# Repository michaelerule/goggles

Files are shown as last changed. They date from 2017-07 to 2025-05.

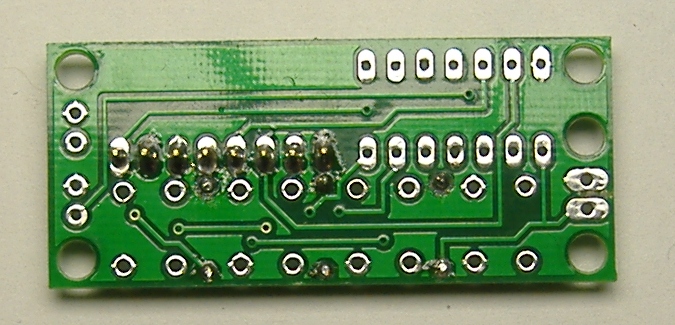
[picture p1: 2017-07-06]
media/visor media/assemble/DSCF3167.JPG

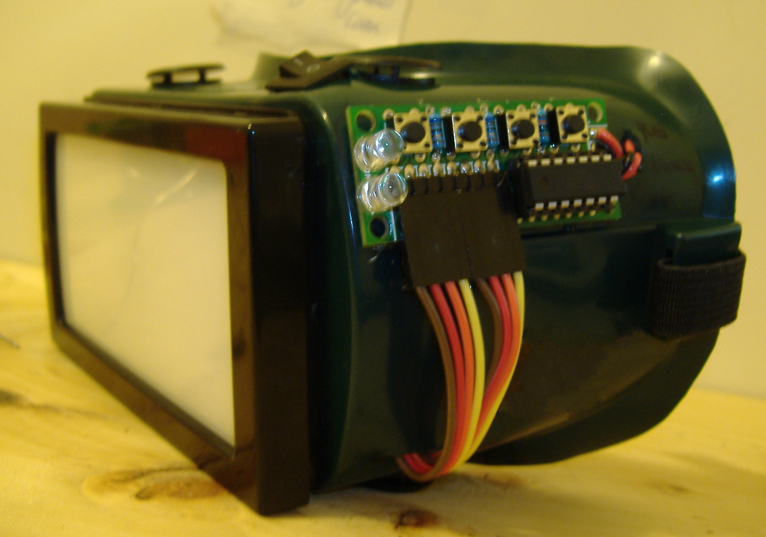
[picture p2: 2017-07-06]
media/visor media/assemble/DSCF3302.JPG

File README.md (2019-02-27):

# Goggles

Firmware and documentation for flicker-phosphene hallucination goggles. Some of the content here can be rendered as HTML, and a browsable website version of this repository can be [accessed through Github pages](https://michaelerule.github.io/goggles/).

This material follows earlier [blog posts](http://wealoneonearth.blogspot.co.uk/2009/09/how-to-build-goggles.html) outlining construction of do-it-yourself goggles to demonstrate the [flicker phosphene](http://journals.plos.org/ploscompbiol/article?id=10.1371/journal.pcbi.1002158) hallucination effect. A small batch of a [simplified re-design using welding goggles](http://treehovse.blogspot.co.uk) was produced a few years ago. 

Unless otherwise specified, media, text, and rendered outputs are licensed under the [Creative Commons Attribution Share Alike 4.0 license](https://choosealicense.com/licenses/cc-by-sa-4.0/) (CC BY-SA 4.0). Source code is licensed under the [GNU General Public License version 3.0](https://www.gnu.org/copyleft/gpl.html) (GPLv3). The CC BY-SA 4.0 is [one-way compatible](https://creativecommons.org/compatiblelicenses) with the GPLv3 license. The intent of this licensing choice is to encourage academic norms for citation and attribution. 

This project is published in the spirit (but not the letter) of the [tongue-and-cheek CRAPL license for academic code](http://matt.might.net/articles/crapl/CRAPL-LICENSE.txt). This is not a legal license as it contains internal inconsistencies (like forbidding users to exist). However, it contains a strong caution that this project has not been reviewed or prepared for use by the general public. If there is community interest in a specific subset of the project, please open an issue for improving the organization and documentation.

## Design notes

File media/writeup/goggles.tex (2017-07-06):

\documentclass[11pt]{scrartcl}

\newenvironment{itemised}{
\begin{itemize}
  \setlength{\itemsep}{1pt}
  \setlength{\parskip}{0pt}
  \setlength{\parsep}{0pt}
}{\end{itemize}}

\usepackage{hyperref}
\hypersetup{
    colorlinks,
    citecolor=black,
    filecolor=black,
    linkcolor=black,
    urlcolor=black
}

\setlength{\parskip}{0pt}
\setlength{\parsep}{0pt}
\setlength{\headsep}{0pt}
\setlength{\topskip}{0pt}
\setlength{\topmargin}{0pt}
\setlength{\topsep}{0pt}
\setlength{\partopsep}{0pt}

\usepackage{graphicx}
\setcounter{secnumdepth}{5}
\setcounter{tocdepth}{5}
\usepackage[margin=0.72in]{geometry}
\usepackage[utf8]{inputenc}
\usepackage{amsmath, amsthm, amssymb}
\usepackage{txfonts}
\usepackage{verbatim}
\usepackage{multirow}
\usepackage{booktabs}
\usepackage{indentfirst}

\usepackage{titlesec}
\titleformat{\subsubsection}[runin]% runin puts it in the same paragraph
       {\normalfont\bfseries}% formatting commands to apply to the whole heading
       {\thesubsection}% the label and number
       {0.5em}% space between label/number and subsection title
       {}% formatting commands applied just to subsection title
       [:]% punctuation or other commands following subsection title

\begin{document}
\title{The Goggles}
\subtitle{Kit information for James Rutter at AS220 Labs}
\author{Michael Rule}
\date{}
\maketitle
{\setlength{\parindent}{0cm}{This archive contains all information necessary to produce \emph{The Goggles} hallucination visor kits.}}
\tableofcontents
\newpage
\section{Parts and sources}
\subsection{Parts List}
\begin{itemised}
\item 1 Welding Goggles, "Fixed Front" with square window. Suggest: ``Crews'' brand from MRO supply.
\item 3 1/4'' translucent acrylic laser-cut panels
\begin{itemised}
	\item 1 visor outer panel with quasicrystal design
	\item 1 visor middle panel with LED placement markings
	\item 1 visor inner panel with cutaway for wires
	\end{itemised}
	\item 1 2xAAA battery pack
	\item 1 Visor controller printed circuit board
	\item 1 pre-programmed AtTiny24 microcontroller chip
	\item 1 14 pin DIP chip socket
	\item 1 8-pin right angle male header
	\item 2 4-pin female jumper cables
	\item 2 RGB LEDs
	\item 2 Indicator LEDs, 5 or 3mm, flexible options :
	\begin{itemised}
	\item 1 Blue LED, 1 Ultraviolet LED
	\item 1 Color-Change LED, 1 LED with 3.3 forward voltage ( blue, UV, white, some green )
	\end{itemised}
	\item 2 68$\Omega$ resistors	
	\item 1 10K$\Omega$ resistor   	
	\item 4 6mm through-hole tactile switches
	\item 1 toggle power switch ( small rocker style )
	\item 1 4" to 6" length of 22 gauge wire
	\item 2 60-100mm zip ties
	\item 1 1x2'' (appx) velcro tape
	\item 1 13x18 cm${}^2$ anti-static bag for packaging
\end{itemised}
\newpage
\subsection{Sources}
\subsubsection{Welding Goggles}
Welding Goggles, ``Fixed Front'' with square window. It is important that the model of goggles be designed to fit up to three filter three filter lenses with a gap in the middle. We have previously used  \href{http://www.shoplet.com/Crews-Welding-Goggles-20050/SEPTLS13520050/spdv}{Crews 105-20050} welding goggles. They are the cheapest goggles that meet this requirement. Their price is between \$3 and \$10.   If you use a different product, get a sample and test whether the kit works with that design. MRO center has the best price if ordering large quantities, but their website is hard to navigate. I have seen this item listed twice on their website with over \$2 difference in price. Searching for "Crews Welding Goggles" through google seems to be good about finding the cheapest source.
\subsubsection{1/4'' translucent acrylic laser-cut panels}
You want the ``intermediate'' translucency quarter-inch acrylic panels. I picked mine up from RISD materials store. On some days, there is someone at the store who will cut large sheets down to laser cutter size for you. 
If not, you will have to do it yourself using an acrylic knife or band saw. AS220 Epilog bed size is 18x22''. Cheap-Chinese mystery laser, which was used for the first production run, has a 12''x12'' bed size.
\subsubsection{2xAAA battery pack}
These are available from all electronic distributors ( Mouser, Digikey ), and also available wholesale from China via ebay. Current design uses an open-clip plastic model. The holes on the bottom of this model allow for some flexibility when mounting, and the 3D printed parts have been designed with this form in mind. The small size also lets you keep the batteries on the inside, if you wish.
\subsubsection{Visor controller printed circuit board}
These much be orderd from GoldPhoenix online. The smallest order is 93 boards for USD114. The necessary EagleCad and Gerber files are in this archive. Instructions for purchasing a batch from GoldPoenix can be found on their website. Payment is through PayPal, with ``mass payment'' providing a USD3 discount. Lead time is approximately two weeks.
\subsubsection{pre-programmed AtTiny24 microcontroller chip}
Any of AtTiny24/44/84 will work with this design. I purchase through Mouser.
\subsubsection{14 pin DIP chip socket}
A socket for the microcontroller is not mandatory, but is convenient. It reduces the chance of destroying the microcontroller while soldering, especially for less experienced solderers, and makes it easier to reprogram the device ( although in-place programming is possible with this circuit ). I purchased these from Mouser but they are also very cheap from Futurlec. Ebay is sometimes the best price for this component, after considering shipping.
\subsubsection{8-pin right angle male header}
There are at least three versions of single-row right-angle male break-away headers floating around. We want the ones that Sparkfun sells. These have a plastic buffer that raises the pins to the perfect height to accept a female 4-pin jumper. Check datasheets before you buy. My first order from Futurlec provided headers that were unsuitable. 
\subsubsection{4-pin female jumper cables}
These are not available from any of the major domestic distributors. Ideally, you are looking for 20cm ( 200mm ) long cables, although 30cm may be tolerable. Most of the 30cm cables will be loose wires in an ugly color. \href{http://www.seeedstudio.com/depot/4-pin-dualfemale-jumper-wire-300mm-5-pcs-pack-p-97.html}{Seed studio has them for USD0.60}. \href{http://www.elechouse.com/elechouse/index.php?main_page=product_info&cPath=105_108&products_id=433}{Elechouse is also USD0.60}. \href{http://www.aliexpress.com/store/product/4-Pin-Dual-female-Jumper-Wire-wire-length-200mm-5pcs-bunch/505390_539192964.html}{Ali express has them for USD0.21, but they double their prices in shipping}. Ebay still seems to be the cheapest option. 
\subsubsection{Indicator LEDs} There is flexibility in the indicator LEDs. Both 3mm and 5mm sizes fit, although 3mm fits and looks better. The LEDs need to be able to tolerate up to 3.3V forward volatage, which wil limit you to blue, violet, white, and color-changing LEDs. Color-changing LEDs are cool but expensive. If you use a color changing LED for the play/shuffle indicator, it will be phase reset frequenty -- which may or may not be desirable. 
\subsubsection{Other Components} The remaining components are available from any major distributor, but again, the best prices appear to be on Ebay with no obvious loss in quality.

\subsection{Costs}
Table 1 outlines an optimistic cost estimate for sourcing 93 kits. Most of the cost lies in the boards, the goggles themselvs, laser cutting, microcontrollers, and the jumper wires to the RGB LEDs. A good strategy is to purchase cheap components in lots of 100 then purchase more expensive items as needed. Prices based on a sale for the welding goggles which may not always be available.
\begin{table}[h]
\centering
\begin{tabular}{llllllll}
Item & Source & cost & units & \$/item & items & unit cost\\
\toprule
6mm tactile switch & Ebay & \$16.00 & 400 & 4 & 100 & \$0.17\\
PCB & GoldPhoenix & \$114.00 & 93 & 1 & 93 & \$1.23\\
10k resistor & Ebay & \$1.50 & 100 & 1 & 100 & \$0.02\\
68ohm resistor & Ebay & \$3.69 & 200 & 2 & 100 & \$0.04\\
LED1 & Ebay & \$7.80 & 100 & 1 & 100 & \$0.08\\
LED2 & Ebay & \$5.80 & 100 & 1 & 100 & \$0.06\\
RGB LED & Ebay & \$28.50 & 200 & 2 & 100 & \$0.31\\
14 pin DIP socket & Ebay & \$6.70 & 100 & 1 & 100 & \$0.07\\
4 pin 20cm f-f jumpers & aliexpress & \$94.92 & 200 & 2 & 100 & \$1.02\\
attiny24 & Mouser & \$88.20 & 100 & 1 & 100 & \$0.95\\
rocker switch & Ebay & \$18.89 & 100 & 1 & 100 & \$0.20\\
right-angle male headers & Sparkfun & \$50.00 & 100 & 1 & 100 & \$0.54\\
battery holder & Ebay & \$27.99 & 100 & 1 & 100 & \$0.30\\
crews welding goggles & MRO supply & \$360.64 & 100 & 1 & 100 & \$3.88\\
bags & Ebay & \$15.89 & 100 & 1 & 100 & \$0.17\\
anti static foam & Ebay & \$68.75 & 100 & 1 & 100 & \$0.74\\
acrylic & AS220 & \$100.00 & 100 & 1 & 100 & \$1.08\\
batteries & Ebay & \$44.99 & 200 & 2 & 100 & \$0.48\\
velcro & Ebay & \$8.74 & 100 & 1 & 100 & \$0.09\\
zip ties & Ebay & \$2.43 & 200 & 2 & 100 & \$0.03\\
 \bottomrule
TOTAL & & \$1,065 & & & 93 & \$11.46\\
\end{tabular}
\caption{Highly optimistic cost estimate using all lowest cost sources}
\label{}
\end{table}

\newpage
\section{Firmware source code and uploading}
The source for The Goggles firmware is in the \emph{software} sub-directory.
You need linux, avr-gcc, avrdude, and an AVR-ISP MkII to compile and upload. Uploading instructions are in a comment in the header of the source. The pinouts for connecting the AtTiny to an AVR ISP MkII are repeated below.
\begin{description}
\item[goggles-24.c] Default flicker-hallucination program for AtTiny24.
\item[goggles-24-calm.c] Opens with constant color patches in case you want a partial ganzfeld, no flickering. 
\end{description}
The script "go" runs on linux-like systems ( require sh ) and does the following : 
\begin{itemised}
\item checks to see if your AVR is connected
\item compiles the source code
\item strips the source code down for transfer
\item copies the source code to the AVR
\end{itemised}
Things that might change :
\begin{itemised}
\item "go" assumes that you are using avrispmkII
\item "go" assumes that you are using AtTiny24. Adjust flags accordingly if not.
\item "go" assumes your programmer lies at /dev/ttyUSB0, this may change, especially on macs.
\end{itemised}
\begin{verbatim}
    AtTiny24 pinout:               Programmer pinout, 
                                           6 pin:               10 pin:
                __ __
    3     VCC -|  U  |- GND    1     6 MISO +-+  VCC 3    3 vcc  +-+   MOSI 2
      BCK PB0 -|     |- PA0 G1       5 SCK  + + MOSI 2           + +    
      SHU PB1 -|     |- PA1 B1       4 RST  +-+  GND 1           + +]  RST  4
    4 RST PB3 -|     |- PA2 R1                                   + +   SCK  5 
      PLY PB2 -|     |- PA3 G2                            1 gnd  +-+   MISO 6
      FWD PA7 -|     |- PA4 B2 5 
    2 IND PA6 -|_____|- PA5 R2 6 
    
    Circuit:                                  __ __
                                         VCC-|  U  |-GND
              R-GBR-GB                GND-/ -|     |-----\
     _________||||||||___             GND-/ -|     |------(RGB1)-GND
    |o+++++++ |  ||  |  o|           VCC-www-|     |-www-/
    | +++++++ |__||__|(i)|            GNd-/ -|     |-----\
    |= [x] [<] [=] [>](p)|            GNd-/ -|     |------(RGB2)-GND
    |o__________________o|        GND-(LED1)-|_____|-www-/

                                         VCC-(LED0)-GND
\end{verbatim}

The buttons are as follows, from left to right :
\begin{itemised}
\item[$\times$] Shuffle      : if playing, toggle shuffled playback, else skip to random
\item[$<$] Skip Back    : skips to the previous light patch
\item[$=$] Play/Pause   : toggles automatic advancing through patches
\item[$>$] Skip Forward : advances to the next light patch
\end{itemised}

LEDs indicate :
\begin{itemised}
\item[i] -- indicator LED. on if playing, flashing if playing+shuffle
\item[p] -- power LED, on if powered on. 
\end{itemised}

\newpage
\section{CAD Files and instructions}
\subsection{Laser Cutting}\noindent Laser cutting .svg files are in the \emph{laser cut} sub-directory. The Goggles require 3 laser cut panels
\begin{itemised}
\item quasicrystal or blank patterned exterior panel
\item middle panel with LED placement marks
\item inner panel with notch for wiring
\end{itemised}
The outer and LED panels are cut in two passes. 
\begin{itemised}
\item shallow low-power pass etches vector graphics
\item high-power pass cuts out outline
\end{itemised}
These parts should be cut out of medium translucency 1/8'' acrylic.
Some files have both graphic and outline cuts and must be separated to cut. 
Both passes are vector cuts, not raster graphics. 
Some files have multiple panels with redundant edges removed for fast cutting. 
I suggest making a custom panel with this technique to fit the bed size.
There are also blank panels that can be used as templates for custom graphics.

\subsection{3D printing}
The sub-directory \emph{3d printed} contains two .stl files.
3D printed parts are not a core part of the kit, but rather an extension that
some with access to a 3D printer may want to print or build upon. 
These files contain a bracket for the batteries and board,
as well as a button pad to overlay the board. 
I recommend printing with very little (no) infill, and one or two shells,
using a translucent plastic ( natural ABS will work ) to let the indicator lights
shine through.

\subsection{PCB manufacture}
EagleCad design and Gerber files are in the \emph{PCB} sub-directory. The 'board.zip' archive contains everything needed to order from goldphoenix. Send that archive as-is to order more boards. Goldphoenix offers 1000cm${}^2$ for \$114, which gives you 93 boards at about \$1.25/board.

\section{Media}

\begin{description}
\item[media/instructions] HTML and PDF assembly instructions
\item[media/instructions/insert] Packaging insert
\item[media/artwork] Custom artwork, (c) Austin Redwood, Michael Rule
\item[media/photos] Assembly photos
\item[media/journal.pcbi.1002158.pdf] PLoS computational biology flicker-hallucination paper writeup
\item[media/writeup/optimistic\_cost\_estimate.ods] spreadsheet for cost table in this document
\item[media/writeup] source code for this document
\end{description}
\end{document}

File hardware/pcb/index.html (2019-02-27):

### Index of pcb

../
./Attiny14:24:84
./milledgoggles Arduino pro-mini

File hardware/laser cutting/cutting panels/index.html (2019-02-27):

### Index of cutting panels

../
10_inner copy 2.svg
10_inner copy.svg
10_inner.svg
10_inner_merged.svg
1x1_inner_merged.svg
2_inner_merged.svg
5_cluster_inner_merged.svg
5x1_inner_merged.svg
blank_2x1_merged.svg
blank_2x3.svg
blank_2x3_merged.svg
blank_2x4.svg
blank_2x4_merged.svg
clear4r.svg
clear4test.svg
clear4testPanel.svg
dead_simple.svg
LED_2x3.svg
LED_2x3_merged.svg
LED_2x4.svg
LED_2x4_merged.svg
notched.svg
notched4.svg
quasi_1x1.svg
quasi_2x3.svg
quasi_2x4.svg
quasi_2x4_panel.svg
quasi_eye_1-3-sparser-2x4.svg
quasi_eye_1-3-sparsest.svg
quasi_eye_1-3-sparsester.svg
quasiSpecial6-5.svg
tracequasi.svg

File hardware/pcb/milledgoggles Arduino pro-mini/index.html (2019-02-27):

### Index of milledgoggles Arduino pro-mini

../
drill.rml
mill.rml
Welding_board_3.ai
Welding_board_3.svg

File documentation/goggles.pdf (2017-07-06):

# The Goggles

Kit information for James Rutter at AS220 Labs

## Michael Rule

This archive contains all information necessary to produce The Goggles hallucination visor kits.

## Contents

1 Parts and sources | 2
2 Firmware source code and uploading | 5
3 CAD Files and instructions | 6
4 Media | 6

## 1 Parts and sources

### 1.1 Parts List

- 1 Welding Goggles, ”Fixed Front” with square window. Suggest: “Crews” brand from MRO supply.
- 3 1/4” translucent acrylic laser-cut panels

– 1 visor outer panel with quasicrystal design
– 1 visor middle panel with LED placement markings
– 1 visor inner panel with cutaway for wires
- 1 2xAAA battery pack
- 1 Visor controller printed circuit board
- 1 pre-programmed AtTiny24 microcontroller chip
- 1 14 pin DIP chip socket
- 1 8-pin right angle male header
- 2 4-pin female jumper cables
- 2 RGB LEDs
- 2 Indicator LEDs, 5 or 3mm, flexible options :

– 1 Blue LED, 1 Ultraviolet LED
– 1 Color-Change LED, 1 LED with 3.3 forward voltage ( blue, UV, white, some green )
- 2 68Ω resistors
- 1 10KΩ resistor
- 4 6mm through-hole tactile switches
- 1 toggle power switch ( small rocker style )
- 1 4” to 6” length of 22 gauge wire
- 2 60-100mm zip ties
- 1 1x2” (appx) velcro tape
- 1 13x18 cm²
anti-static bag for packaging

### 1.2 Sources

1.2 Welding Goggles: Welding Goggles, “Fixed Front” with square window. It is important that the model of goggles be designed to fit up to three filter three filter lenses with a gap in the middle. We have previously used Crews 105-20050 (http://www.shoplet.com/Crews-Welding-Goggles-20050/SEPTLS13520050/spdv) welding goggles. They are the cheapest goggles that meet this requirement. Their price is between $3 and $10. If you use a different product, get a sample and test whether the kit works with that design. MRO center has the best price if ordering large quantities, but their website is hard to navigate. I have seen this item listed twice on their website with over $2 difference in price. Searching for ”Crews Welding Goggles” through google seems to be good about finding the cheapest source.

1.2 1/4” translucent acrylic laser-cut panels: You want the “intermediate” translucency quarter-inch acrylic panels. I picked mine up from RISD materials store. On some days, there is someone at the store who will cut large sheets down to laser cutter size for you. If not, you will have to do it yourself using an acrylic knife or band saw. AS220 Epilog bed size is 18x22”. Cheap-Chinese mystery laser, which was used for the first production run, has a 12”x12” bed size.

1.2 2xAAA battery pack: These are available from all electronic distributors ( Mouser, Digikey ), and also available wholesale from China via ebay. Current design uses an open-clip plastic model. The holes on the bottom of this model allow for some flexibility when mounting, and the 3D printed parts have been designed with this form in mind. The small size also lets you keep the batteries on the inside, if you wish.

1.2 Visor controller printed circuit board: These much be orderd from GoldPhoenix online. The smallest order is 93 boards for USD114. The necessary EagleCad and Gerber files are in this archive. Instructions for purchasing a batch from GoldPoenix can be found on their website. Payment is through PayPal, with “mass payment” providing a USD3 discount. Lead time is approximately two weeks.

1.2 pre-programmed AtTiny24 microcontroller chip: Any of AtTiny24/44/84 will work with this design. I purchase through Mouser.

1.2 14 pin DIP chip socket: A socket for the microcontroller is not mandatory, but is convenient. It reduces the chance of destroying the microcontroller while soldering, especially for less experienced solderers, and makes it easier to reprogram the device ( although in-place programming is possible with this circuit ). I purchased these from Mouser but they are also very cheap from Futurlec. Ebay is sometimes the best price for this component, after considering shipping.

1.2 8-pin right angle male header: There are at least three versions of single-row right-angle male break-away headers floating around. We want the ones that Sparkfun sells. These have a plastic buffer that raises the pins to the perfect height to accept a female 4-pin jumper. Check datasheets before you buy. My first order from Futurlec provided headers that were unsuitable.

1.2 4-pin female jumper cables: These are not available from any of the major domestic distributors. Ideally, you are looking for 20cm ( 200mm ) long cables, although 30cm may be tolerable. Most of the 30cm cables will be loose wires in an ugly color. Seed studio has them for USD0.60. (http://www.seeedstudio.com/depot/4-pin-dualfemale-jumper-wire-300mm-5-pcs-pack-p-97.html) Elechouse is also USD0.60. (http://www.elechouse.com/elechouse/index.php?main_page=product_info&cPath=105_108&products_id=433) Ali express has them for USD0.21, but they double their prices in shipping. (http://www.aliexpress.com/store/product/4-Pin-Dual-female-Jumper-Wire-wire-length-200mm-5pcs-bunch/505390_539192964.html) Ebay still seems to be the cheapest option.

1.2 Indicator LEDs: There is flexibility in the indicator LEDs. Both 3mm and 5mm sizes fit, although 3mm fits and looks better. The LEDs need to be able to tolerate up to 3.3V forward volatage, which wil limit you to blue, violet, white, and color-changing LEDs. Color-changing LEDs are cool but expensive. If you use a color changing LED for the play/shuffle indicator, it will be phase reset frequenty – which may or may not be desirable.

1.2 Other Components: The remaining components are available from any major distributor, but again, the best prices appear to be on Ebay with no obvious loss in quality.

### 1.3 Costs

Table 1 outlines an optimistic cost estimate for sourcing 93 kits. Most of the cost lies in the boards, the goggles themselvs, laser cutting, microcontrollers, and the jumper wires to the RGB LEDs. A good strategy is to purchase cheap components in lots of 100 then purchase more expensive items as needed. Prices based on a sale for the welding goggles which may not always be available.

Item | Source | cost | units | $/item | items | unit cost
6mm tactile switch | Ebay | $16.00 | 400 | 4 | 100 | $0.17
PCB | GoldPhoenix | $114.00 | 93 | 1 | 93 | $1.23
10k resistor | Ebay | $1.50 | 100 | 1 | 100 | $0.02
68ohm resistor | Ebay | $3.69 | 200 | 2 | 100 | $0.04
LED1 | Ebay | $7.80 | 100 | 1 | 100 | $0.08
LED2 | Ebay | $5.80 | 100 | 1 | 100 | $0.06
RGB LED | Ebay | $28.50 | 200 | 2 | 100 | $0.31
14 pin DIP socket | Ebay | $6.70 | 100 | 1 | 100 | $0.07
4 pin 20cm f-f jumpers | aliexpress | $94.92 | 200 | 2 | 100 | $1.02
attiny24 | Mouser | $88.20 | 100 | 1 | 100 | $0.95
rocker switch | Ebay | $18.89 | 100 | 1 | 100 | $0.20
right-angle male headers | Sparkfun | $50.00 | 100 | 1 | 100 | $0.54
battery holder | Ebay | $27.99 | 100 | 1 | 100 | $0.30
crews welding goggles | MRO supply | $360.64 | 100 | 1 | 100 | $3.88
bags | Ebay | $15.89 | 100 | 1 | 100 | $0.17
anti static foam | Ebay | $68.75 | 100 | 1 | 100 | $0.74
acrylic | AS220 | $100.00 | 100 | 1 | 100 | $1.08
batteries | Ebay | $44.99 | 200 | 2 | 100 | $0.48
velcro | Ebay | $8.74 | 100 | 1 | 100 | $0.09
zip ties | Ebay | $2.43 | 200 | 2 | 100 | $0.03
TOTAL | | $1,065 | | | 93 | $11.46

Table 1: Highly optimistic cost estimate using all lowest cost sources

## 2 Firmware source code and uploading

The source for The Goggles firmware is in the software sub-directory. You need linux, avr-gcc, avrdude, and an AVR-ISP MkII to compile and upload. Uploading instructions are in a comment in the header of the source. The pinouts for connecting the AtTiny to an AVR ISP MkII are repeated below.

goggles-24.c Default flicker-hallucination program for AtTiny24.

goggles-24-calm.c Opens with constant color patches in case you want a partial ganzfeld, no flickering.

The script ”go” runs on linux-like systems ( require sh ) and does the following :

- checks to see if your AVR is connected
- compiles the source code
- strips the source code down for transfer
- copies the source code to the AVR

Things that might change :

- ”go” assumes that you are using avrispmkII
- ”go” assumes that you are using AtTiny24. Adjust flags accordingly if not.
- ”go” assumes your programmer lies at /dev/ttyUSB0, this may change, especially on macs.
AtTiny24 pinout: | Programmer pinout,
| | | | | 6 pin: | | | 10 pin:
__ __
3 | VCC -| | U | |- GND | 1 | 6 MISO +-+ | VCC 3 | 3 vcc | +-+ | MOSI 2
BCK PB0 -| | |- PA0 G1 | 5 SCK | + + MOSI 2 | + +
SHU PB1 -| | |- PA1 B1 | 4 RST | +-+ | GND 1 | + +] | RST | 4
4 RST PB3 -| | |- PA2 R1 | + + | SCK | 5
| PLY PB2 -| | | |- PA3 G2 | | | | 1 gnd | +-+ | MISO 6
FWD PA7 -| | |- PA4 B2 5
2 IND PA6 -|_____|- PA5 R2 6
Circuit: | __ __
VCC-| | U | |-GND
R-GBR-GB | GND-/ -| | |-----\
_________||||||||___ | GND-/ -| | |------(RGB1)-GND
|o+++++++ | | || | | | o| | VCC-www-| | |-www-/
| +++++++ |__||__|(i)| | GNd-/ -| | |-----\
|= [x] [<] [=] [>](p)| | GNd-/ -| | |------(RGB2)-GND
|o__________________o| | GND-(LED1)-|_____|-www-/

VCC-(LED0)-GND
The buttons are as follows, from left to right :

× Shuffle : if playing, toggle shuffled playback, else skip to random < Skip Back : skips to the previous light patch
= Play/Pause : toggles automatic advancing through patches
> Skip Forward : advances to the next light patch

LEDs indicate :

i – indicator LED. on if playing, flashing if playing+shuffle p – power LED, on if powered on.

## 3 CAD Files and instructions

### 3.1 Laser Cutting

Laser cutting .svg files are in the laser cut sub-directory. The Goggles require 3 laser cut panels

- quasicrystal or blank patterned exterior panel
- middle panel with LED placement marks
- inner panel with notch for wiring

The outer and LED panels are cut in two passes.

- shallow low-power pass etches vector graphics
- high-power pass cuts out outline

These parts should be cut out of medium translucency 1/8” acrylic. Some files have both graphic and outline cuts and must be separated to cut. Both passes are vector cuts, not raster graphics. Some files have multiple panels with redundant edges removed for fast cutting. I suggest making a custom panel with this technique to fit the bed size. There are also blank panels that can be used as templates for custom graphics.

3.2 3D printing

The sub-directory 3d printed contains two .stl files. 3D printed parts are not a core part of the kit, but rather an extension that some with access to a 3D printer may want to print or build upon. These files contain a bracket for the batteries and board, as well as a button pad to overlay the board. I recommend printing with very little (no) infill, and one or two shells, using a translucent plastic ( natural ABS will work ) to let the indicator lights shine through.

### 3.3 PCB manufacture

EagleCad design and Gerber files are in the PCB sub-directory. The ’board.zip’ archive contains everything needed to order from goldphoenix. Send that archive as-is to order more boards. Goldphoenix offers 1000cm² for $114, which gives you 93 boards at about $1.25/board.

## 4 Media

media/instructions HTML and PDF assembly instructions

media/instructions/insert Packaging insert

media/artwork Custom artwork, (c) Austin Redwood, Michael Rule

media/photos Assembly photos

media/journal.pcbi.1002158.pdf PLoS computational biology flicker-hallucination paper writeup

media/writeup/optimistic cost estimate.ods spreadsheet for cost table in this document

media/writeup source code for this document

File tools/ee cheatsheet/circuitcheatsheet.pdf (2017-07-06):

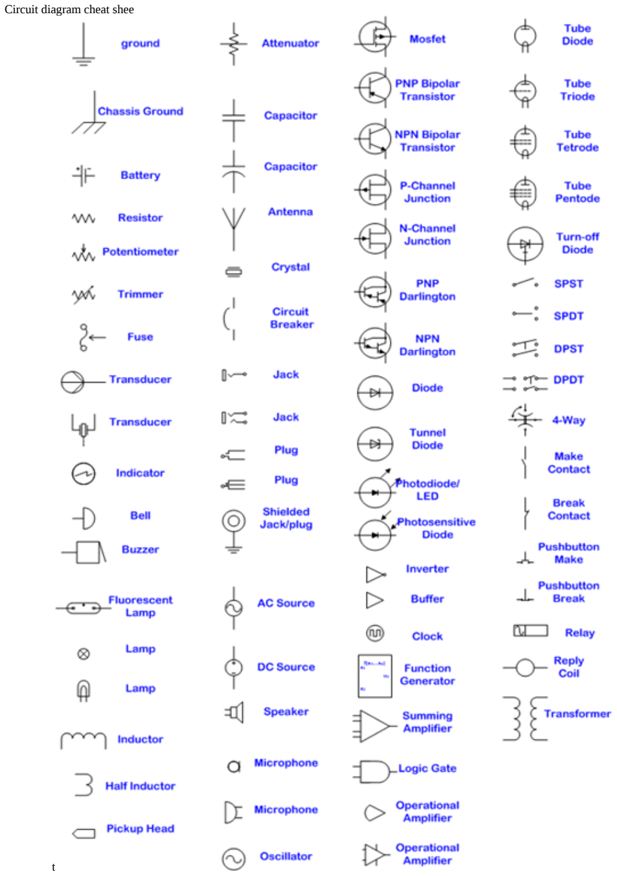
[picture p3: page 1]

Circuit diagram cheat shee

t

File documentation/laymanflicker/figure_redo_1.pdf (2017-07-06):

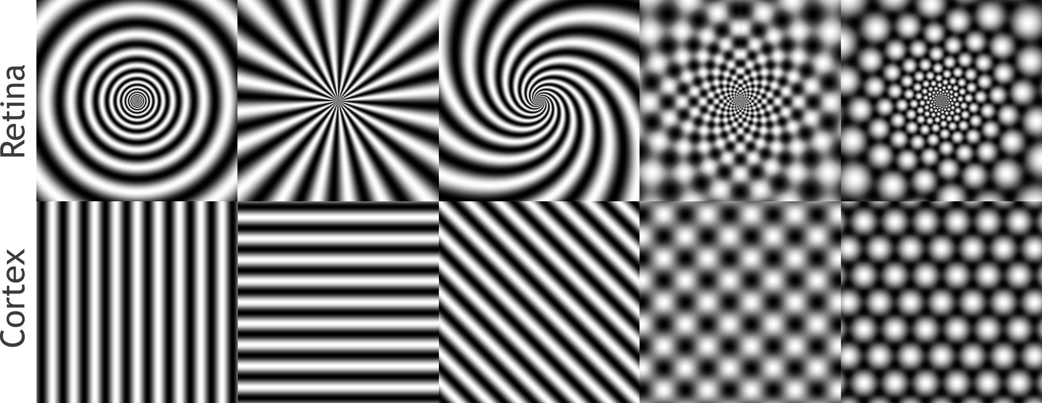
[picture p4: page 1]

RetinaCortex

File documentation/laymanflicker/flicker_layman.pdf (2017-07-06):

Geometric hallucinations induced by flickering light

Most people see colorful geometric patterns when looking at uniform flickering lights of a certain frequency. These patterns are subjectively described as “checkerboards” “ripples” “starbursts” “honeycombs”, sometimes taking on an overall tunnel-like appearance. It is striking how universal these patterns are – these simple flicker-induced geometric hallucinations are similar across individuals, and similar to certain visual hallucinations seen in visual-triggered epilepsy, migraine auras, and hallucinogens. A simple way to achieve such hallucinations is to close one's eyes and face toward the sun. Then, with fingers outstretched and separated, wave the hand back and forth in front of the eyes. Your fingers will create a flickering of the sunlight, which will be diffused and made uniform by closed eyelids.

The shortest primer on the visual system

To understand why flickering lights might trigger geometric hallucinations, and why the hallucinations should take on particular forms, we need to understand a little about the nervous system. A good review is beyond the scope of this article, but I attempt to give a short overview here.

Very briefly, the eye and the brain contain cells called neurons which are specialized for computation. Neurons communicate with each other in little all-or-nothing events called action potentials or “spikes”, which propagate along long “wires” called axons, extending away from the cell body. These spikes are picked up by other neurons with more local tree of wires called “dendrites”. When discussing a large number of neurons, people sometime just think of their average “firing rate” or “activity”, rather than individual spikes.

Early visual processing relates to the sort of geometric hallucinations that we can get out of the early visual system. Light enters the eyes and is picked up by photoreceptor cells. These cells communicate to neurons in the retina that compress visual input. We will focus on four aspects of this compression related to flicker induced geometric visual hallucinations:

(1) The RGB color-space picked up by the photo-receptors is converted to three contrasts : light-dark, yellow-blue, and red-green. The color-space conversion relates to how, for instance, a red-green flicker is especially effective at eliciting hallucinations.
(2) The image is converted to a form focusing on edges and contrasts – uniform areas are ignored. This band-pass nature of early visual processing relates to how neurons are connected in the visual cortex, which in turns determines what size “waves” might appear in geometric visual hallucinations.
(3) The retina has band-pass properties in time as well: slowly changing visual inputs are not registered. This is important for the temporal aspect of flicker induced hallucinations. Certain speeds of flickering will be picked up and transmitted better.
(4) The eye has the greatest resolution in the very center, and the resolution drops off toward the periphery. This is why, for example, it is difficult to read things out of the corner of your eye. The brain also devotes less space to processing the periphery. The way that the visual field is “unfolded” in the brain determines the subjective appearance of spontaneous ( hallucinated ) neural activity.

A theory of geometric visual hallucinations

A theory on the origin of geometric visual hallucinations comes from Ermentrout and Cowen (1979), and briefly, makes the following hypotheses:
– The tunnel-like appearance of the overall hallucination relates to how the brain maps the visual field. – Patterns like checkerboards and honeycombs arise from superposition of multiple waves
– Local interactions in the brain generate wave-like patterns of activity

The two halves of the visual field are split apart and each processed in one half of the brain. The brain devotes more processing power toward the center of the visual field. The net effect is to “unfold” the circular visual field from the retina into a “strip” of the brain at the back called the primary visual cortex. The result is that tunnel-like visual inputs map to simple regular patterns in the brain, and the inverse: hallucinated simple regular patterns in visual cortex are subjectively experienced as tunnel-like visual inputs.

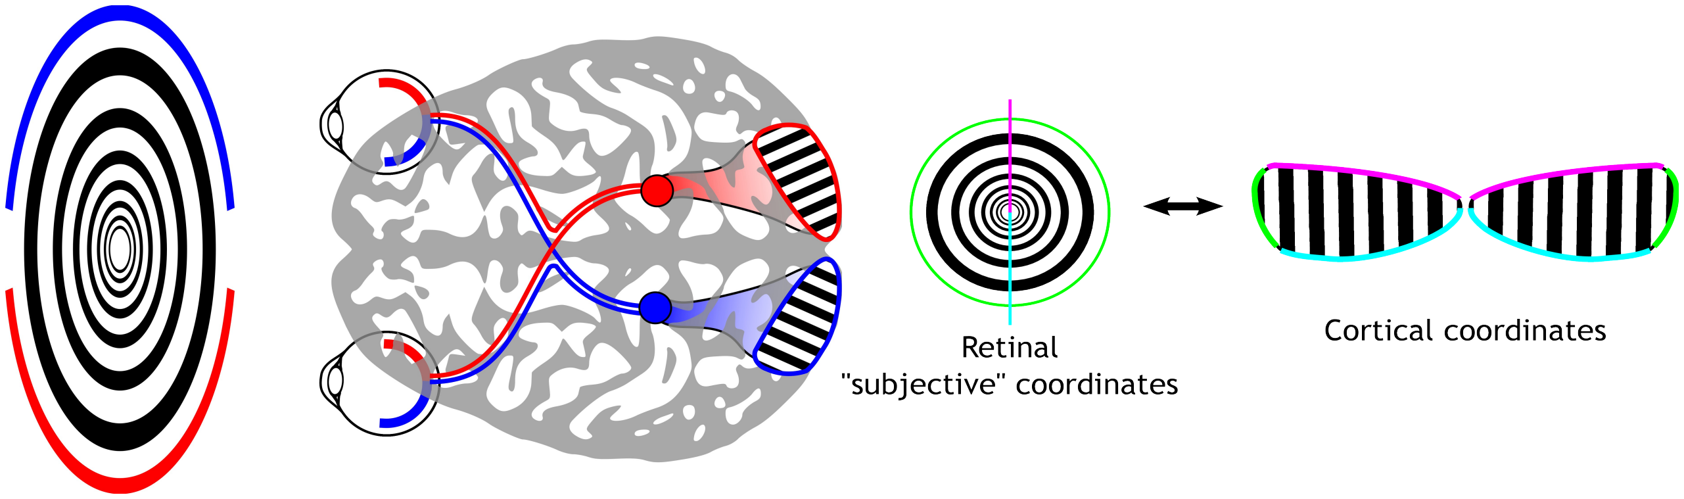
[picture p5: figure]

Stripe-like waves of activity in the brain are sufficient to explain circular, spiral, and starburst hallucinations. Checkerboards can be explained as the sum of two waves at right-angles, and honeycombs can be explains as the sum of three evenly spaced plane waves.

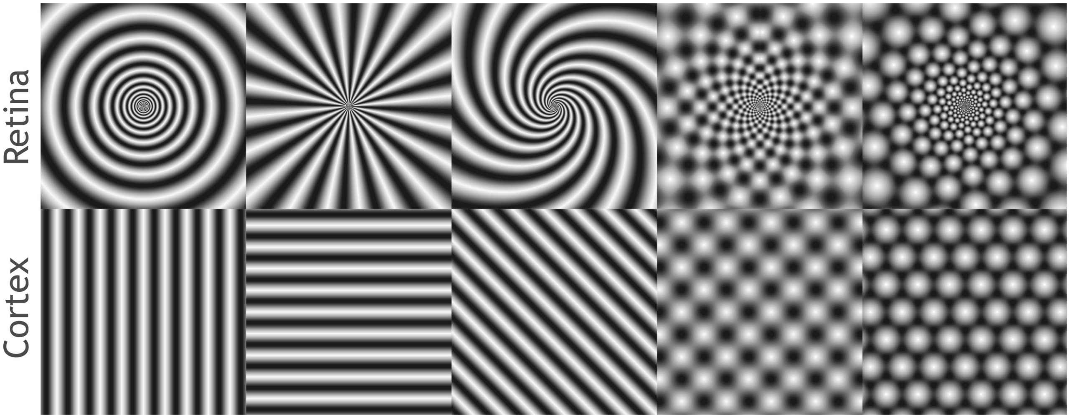
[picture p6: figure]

As to why the brain should spontaneously form waves of activity – that is something of an open question. Qualitatively, one can of it as the brain trying to “find” patterns in an image. Under certain circumstances, the pattern finding circuitry becomes unstable, and tends toward these simple, wave-like

patterns.

Driving the brain with a uniform, flickering input

Flickering light is believed to excite patterns using a resonance effect that pushes visual cortex outside of its normal operation. Neural activity in the brain oscillates spontaneously. There is a natural 8-12Hz oscillation in the visual system called the “alpha rhythm”. Providing visual input at this frequency is believed to excite this intrinsic oscillation. Other frequencies work as well, and may interact with other intrinsic oscillations. Stimulation at 8-25Hz also works to excite the alpha oscillation. Even though this is twice the intrinsic frequency of the system, local patches of the brain are hypothesized to respond only to every-other oscillation cycle, effectively oscillating at alpha. These frequencies vary from person to person and factors not completely understood, and there may be other processes contributing to flicker hallucinations that we have yet to understand.

Modeling the visual system as a “neural field”

Why does making visual cortex “resonate” with a stimulus lead to pattern formation?

[[ I don't know how to treat this without a lot of technical detail ]]

The response of a neural field model to uniform, flickering stimuli

[[ I don't know how to treat this without a lot of technical detail ]]

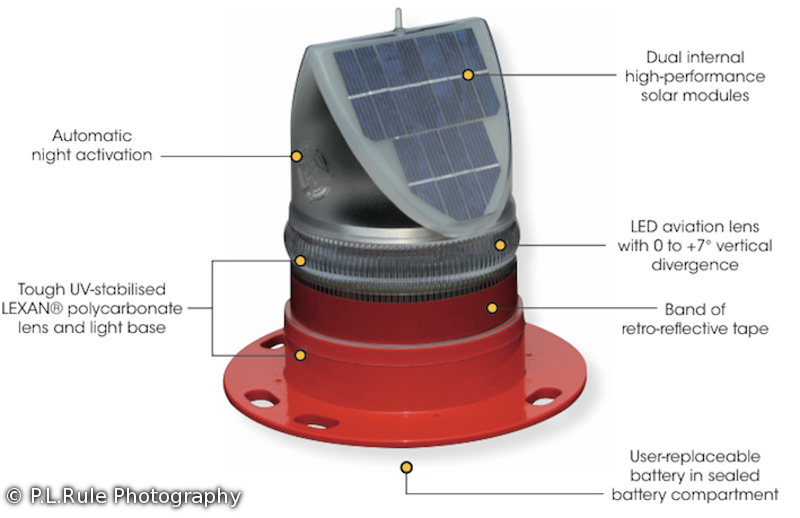
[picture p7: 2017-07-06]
tools/ee cheatsheet/media/Technical LED Color Chart_files/watermarked 105010_specs_pic_large.png

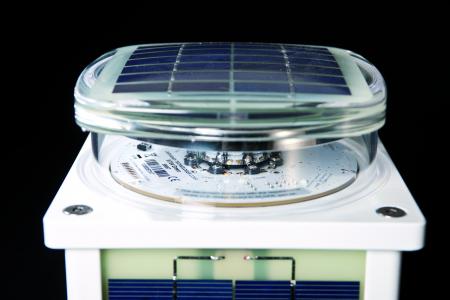
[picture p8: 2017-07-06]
tools/ee cheatsheet/media/Technical LED Color Chart_files/1029684-specs_large.JPG

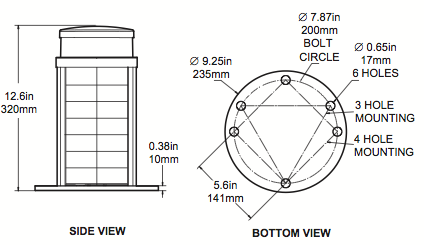
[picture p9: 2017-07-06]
tools/ee cheatsheet/media/Technical LED Color Chart_files/1029684-specs4_large.jpg

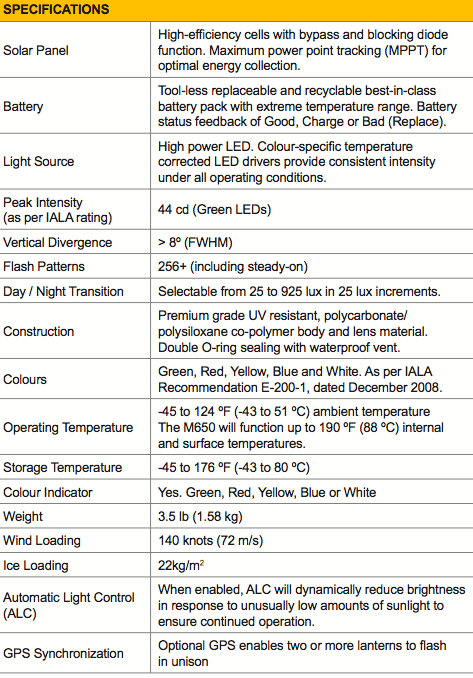
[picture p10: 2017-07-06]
tools/ee cheatsheet/media/Technical LED Color Chart_files/102943-specs7_large.jpg

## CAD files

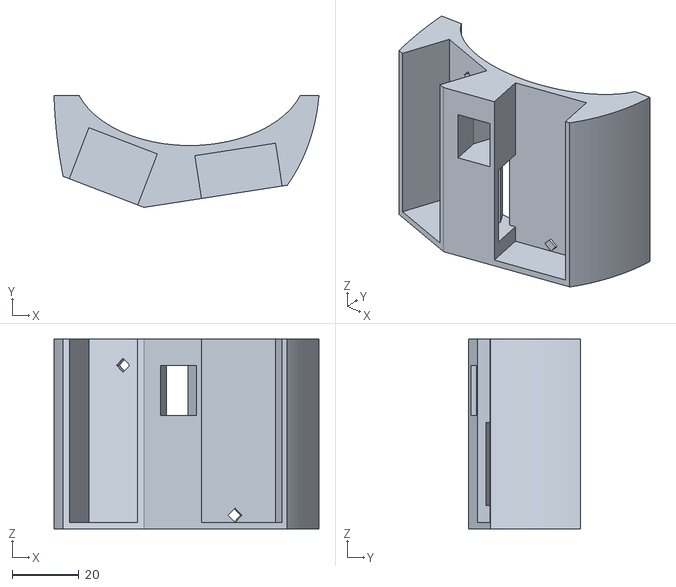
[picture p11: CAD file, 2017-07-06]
hardware/3d printing/3d printed/g1.stl
79.5 x 33.6 x 57.0

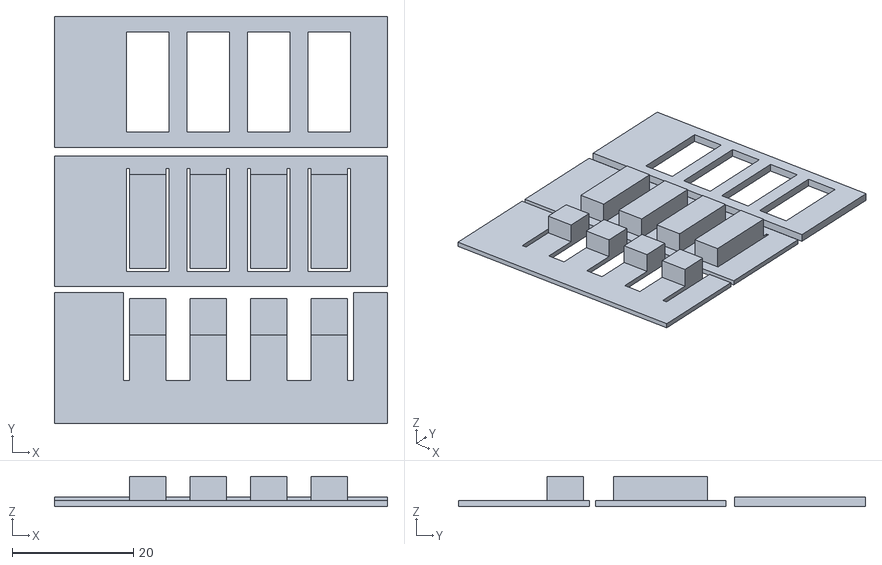
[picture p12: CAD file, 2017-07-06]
hardware/3d printing/3d printed/b1.stl
55.0 x 67.2 x 5.00

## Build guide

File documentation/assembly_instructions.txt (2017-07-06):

Assembly Instructions

Take a look at these pictures of the finished project to get a good idea of how everything is going to fit together when it's done.

Phase 1: The board

Prepare you soldering station and heat up your soldering iron. 

Make sure you have all parts pictured here. Listed from top to bottom, left to right, in the picture shown :

A   1 5" length of 22 gauge wire
B   2 RGB LEDs
D   2 68Ω resistors
C   1 10KΩ or 100KΩ resistor
E   1 2xAAA battery pack
F   1 pre-programmed AtTiny24 microcontroller
G   1 14 pin DIP chip socket
H   1 8-pin right angle male header
I   1 Visor controller printed circuit board
J   1 Blue LED
K   1 Ultraviolet LED
L   1 toggle power switch
M   4 tactile switches
N   2 4-pin female jumper cables

Locate the three resistors and bend the leads at a right angle close to the body, as shown. The LED resistors are 68ohm ( blue grey black gold ). The reset pull-up resistor is 100Kohm ( brown black orange gold ). However, as these were ordered from China, the markings are a bit unusual, and instead look like brown, black, black, orange, gold. The resistor value is, however, correct. Insert the resistors into the board. The two 68 ohm resistors go on the right, at shown, in the slots marked "LED". The reset pull-up resistor goes in the slot on the left marked "10k". Optionally bend the leads outward to hold the resistors in place while you solder them. Solder the resistors, and trim the excess leads with a wire cutter.

Place the 8-pin right-angle connector for the RGB LED cables as shown. Note that the plastic part of the header should surround the part of the header that is parallel to the board. Turn the board over and solder the 8-pin right angle connector. A common trick to get the connector flush against the board is to solder one pin. Then, melt that solder joint while pressing the connector flush against the board, and let it cool again. Solder the remaining pins.

Place the tactile switches on the board as shown. Note that, if the tactile switches are places sideways, the board will not function. 

Solder the chip socket. Note that there is a U shaped notch in one side of the socket. This indicates the orientation of the socket. Place the socket so that this notch is on the left as shown. One trick to get the socket flush against the board is to solder one corner pin, then melt that solder joint, position the socket so that it is flush, and let the joint cool. Then, do the same thing on the opposite corner. The socket is now held in place, leaving you free to solder the remaining pins.

Solder the indicator LEDs. It is important to insert these LEDs in the correct direction, otherwise they will not light. The LED has two leads. One leads is the "ground" LED. This lead will be shorter. IF you look closely at the plastic part of the LED, the base on one side will be flat. This also indicates the side of the LED with ground lead. In our case, thr ground lead should be at the top, as pictured here. Solder both indicator LEDs. One will be purple and one will be blue, but it does not matter which one goes where.

Trim any extra leads sticking out of the bottom of the board with wire snips.

Locate the AtTiny24 microcontroller chip. Note that one end of the chip has a U shaped notch, just like the socket. This indicates the orientation of the chip, and its important to insert the chip in the correct direction, otherwise the board will not work. The notch should be on the left as pictured. Carefully insert the microcontroller into its socket.

B : the goggles.

We are going to modify a pair of welding goggles to make the Visor. 

Slide the outer bracket of the goggles, and remove the tinted and clear plastic plates from the welding goggles. Leave the metal bracket.

Locate the translucent white plastic pieces that came with your kit. There should be three of them. One has a small notch cut into the side. This notch is for with LED wired, and will go inside. Another has a picture of some LEDs etched into the surface. This is the inner panel, and you will attach the LEDs to its surface. The third has a decorative pattern etched into its surface. This panel goes on the outside. 

Stack the inner panel on top of the decorative panel, so that the LED markings are on the bottom surface and the decorative markings are on the top. Place these pieces into the goggles where the tinted plastic used to be, and slide the bracket closed again. You should see a decorative pattern on the front of the goggles, and markings for positioning the LEDs on the inside of the goggles.

Get out your x-acto or hobby knife, and do be careful.

We are going to make some cuts into the goggles to pass wires through, and also a place to hold the power switch. 

Observe the markings in this picture. You can attach the electronics in many creative ways, but this is the way I assembled it. Wherever you decide to place the board, cut a small slit for the power wires near the power connector on the board ( the one remaining un-soldered place on the board ). Also, at some distance away from the 8 pin right angle connector for the LEDs, cut a 3/4" 1.5cm long slit for the LED cables. 

The power switch is best placed at the top, as pictured. Draw a rectangluar outline slightly smaller than the top of the power switch, and remove it with a x-acto knife. Try to insert the power switch into the hole for a test, and adjust the size of the hold if necessary.

Solder the red (+) wire from the battery pack onto one lead of the power switch, and the red jumper wire onto the other. Insert the power switch into the goggles as shown below.

Run the black ( -, ground ) wire from the batter pack, as well as the red (+) jumper wire connected to the switch, out through the slit you made for the power cables. 

We are going to solder the power wires into the board. Wires that are soldered directly onto the board often come loose. One simple way to make the connection stronger is to tie the wires to the board before you solder them. If you find this too challenging, it is not strictly necessary, as there shouldn't be too much strain on the power wires in typical use. 

Solder the power cables as shown, making sure that the red (+) wire goes into the hole labeled "+3v", and the black (-) wire in the other pad with the filled in white marking. Optionally, use the knot trick as shown to reduce strain on this solder connection.

If you have two AAA batteries, you can put them in the battery holder and turn on the power switch to see if the boiard works. The power-on LED should light up if everything is working correctly. If this does not happen, you will need to troubleshoot the board. Check that the indicator LEDs are inserted in the correct orientation, and that the red (+) wire from the batter is indeed connection to the +3v marked pad on the board. Look for loose or broken solder connections, and make sure the batteries you are using to test are charged.

Next, we are going to wire up and place the red, green, and blue (RGB) LEDs which generate the flickering light pattern.

Attach the jumper cables for the LEDs to the 8-pin connection as shown below. Their orientation does not matter, though for consistancy you should orient them the same way. Pat attention to the markings underneath the header, which have the labels "R", "G", and "B" for "red", "green", and "blue" color channels, as well as a filled-in white region indicating the groun (-) pin for the LEDs. You will want to rememebr which color wire corresponds to the ground pins for later.

Thread the jumper cables one after another through the slit you prepared earlier.

The inside of the goggles should now look something like this. Next we're going to insert the colored LEDs into the viewing area. These are the LEDs with four leads. In order, these leads are R(ground)GB. Examine the RGB LEDs closely. Like the indicator LEDs, one side of the plastic housing is flat on the bottom. As before, this indicates the side of the LED with the ground lead. You will want to insert the LEDs into the jumper cables such that the ground lead of the LED matches up with whicever color wire is the ground wire, which was noted in the previous step. 

You may optionally want to trim the LED leads to all the same length to make inserting the LEDs into the jumpers easier, or to adjust the spacing between the LEDs.

Turn on the goggles and test that the RGB LEDs are working. The first pattern on the goggles is a white flickering stimulus. If either LED does not appear white, you may have some missed connections. Try adjuting the LEDs and trimming the leads slightly if you are not getting a connection. If that fails, check that the jumpers are placed securely on the board header, and that the board header is soldered completely. If all color channels of both LEDs are working, turn of the goggles and proceed. 

Now, glue the LEDs in place as indicated by the etched markings, and as demonstrated here. Either super glue or hot glue will work. I found the gluing the ends of the jumpers together with a bit of super glue first made positioning easier. You may want to tack down the LED wires as shown to keep them in place. 

Insert the inner translucent plastic piece, feeding the wires out through the notch provided.

You're goggles are nearly complete ! The only thing left to do is to tie down some loose ends and hold everything in place.

Glue the battery pack in position as shown. 

Optionally glue the circuit board down to the outside of the goggles, or use the holes provided for other fasteners, perhaps zip ties. 

Organize the wires on the inside and move them out of the field of view. Tack everything down with some glue to hold it in place.

Thats it, you're done!

Power on the goggles and take note of the tacticle switches. They are, in order

-- shuffle
-- -- will jumpt to a random preset 
-- previous
-- -- will jump to the previous preset
-- play / pause
-- -- toggles automatic advancements through presets
-- next
-- -- will jump to the next preset

so, with that in mind, put on the goggles and take them for a spin

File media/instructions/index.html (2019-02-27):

### Index of instructions

../
./website
assembly_instructions.txt
goggles instructions narrow.pdf
insert.pdf
using the goggles

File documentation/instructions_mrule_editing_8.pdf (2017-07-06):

A word of warning :

THE VISOR IS NOT FOR EVERYONE. SOME PEOPLE HAVE A FROM OF EPILEPSY THAT CAN BE TRIGGERED BY FLICKERING LIGHTS. DO NOT USE THE VISOR IF YOU HAVE PHOTOSENSITIVE EPILEPSY.

Whats going on here?

Many people see geometric patterns when looking at flickering lights. The patterns depend on the frequency, color, and intensity of the flickering. People report seeing similar shapes, which are common in visual hallucinations and are called “form constants”. Flicker hallucinations are best induced using a totally immersive and uniform visual stimulation called a ganzfeld, which is German for “entire field”. Although the Visor is not a complete ganzfeld, it is immersive enough to demonstrate the flicker hallucination effect. The Visor has been carefully programmed and tuned to display a wide range of colorful patterns, allowing you to experience how geometric visual hallucinations change with frequency and color.

How does it work?

Flickering lights confuse the eye and the brain, causing them to misinterpret what they’re seeing. One hypothesis is that the flickering interacts with natural ongoing oscillations in visual cortex, exciting a specific frequency of brain waves. This increases the activity in visual cortex enough to overload the circuitry the brain uses for interpreting what it sees, causing you to see things that aren’t really there. One model has shown that flickering lights can cause visual cortex to behave like a ‘reaction diffusion system’, which is a type of system that spontaneously forms patterns. The most famous examples of biological reactiondiffusion systems are the patterns in animal fur, like leopard spots and zebra stripes. Some common geometric visual hallucinations induced in flicker hallucinations include stripes, checkerboards, hexagons, circles, and spirals. For a more detailed background, as well as a hypothetical mathematical model of the flicker hallucination effect, visit the publication linked at is.gd/qvMFol.

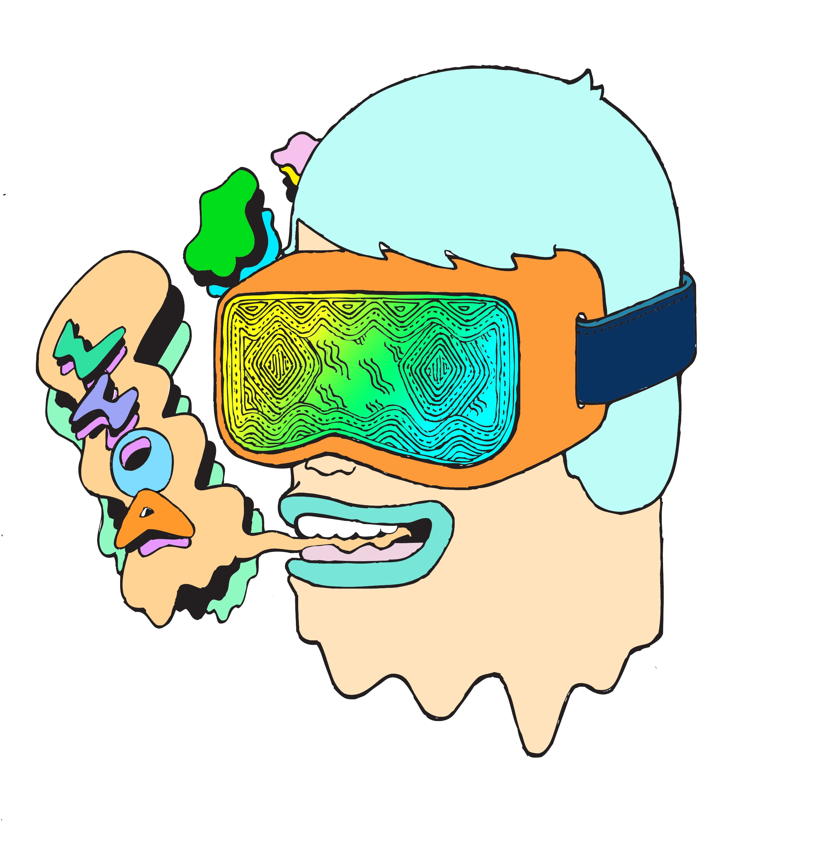
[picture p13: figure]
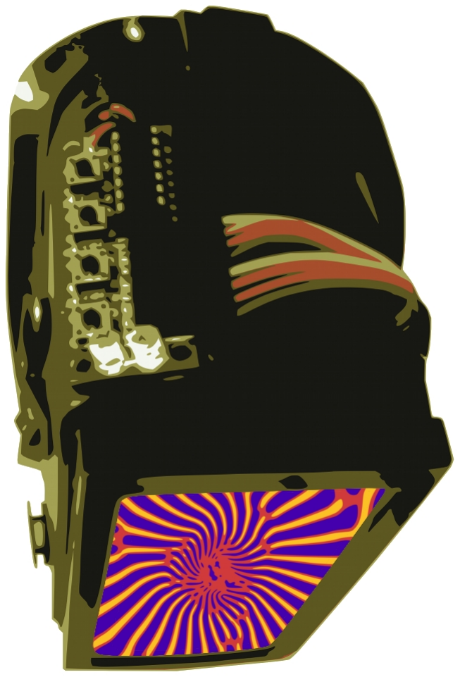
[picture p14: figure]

Assembly:

Assembly instructions are hosted online at treehovse.blogspot.com or is.gd/u5BvNb. Note that's treehovse with a 'v' instead of a 'u'. Visit this website to learn how to build your Visor kit.

In this parts bundle should be :

1 visor outer panel with quasicrystal design
1 visor middle panel with LED placement markings 1 visor inner panel with cutaway for wires
1 2xAAA battery pack
1 Visor controller printed circuit board
1 preprogrammed AtTiny24 microcontroller chip 1 14 pin DIP chip socket
1 8-pin right angle male header
2 4-pin female jumper cables
2 RGB LEDs
1 Blue LED
1 Ultraviolet LED
2 68 resistors Ω
1 10K resistor Ω
4 tactile switches
1 toggle power switch
1 4" to 6" length of 22 gauge wire

Along with your parts bundle, you should also have received one pair of welding goggles.

You will also need these tools and materials, not included in the kit :

A hot glue gun and hot glue sticks
A soldering iron and solder
Wire cutters
X-acto knife or hobby knife
optionally : super glue

Assembly instructions are hosted online at www.treehovse.blogspot.com, which is linked to the shortened URL is.gd/u5BvNb. Visit this website to learn how to build your Visor kit.

Experiment !

Once you have constructed the Visor, try drawing what you see, and comparing the experience with a friend. Start to experiment. Do different people see the same things? Does the experience seem to change when you are more alert, or more tired, or with open or closed eyes? Do you see the same patterns on the same presets across different days? If all of that gets too serious, the Visor also makes and excellent costume addition for partying, or simply creating a spectacle.

Usage Instructions:
Here is a cartoon of the board :

The buttons are as follows, from left to right :

Shuffle lights if playing, skip to random if paused Skip to the previous light patch
Play/Pause: toggles automatic playback
Skip to the next light patch

When first turned on, the goggles are paused at the first patch.
Press play/pause to begin the light sequence.
Press forward and back to move through the light patches.
Press shuffle to skip to a random patch when paused, or turn on randomized playback while playing.

The LEDs indicate :

is on if playing, flashing if playing with shuffle power LED is on if powered on.

When the goggles are paused, the indicator light will be off. When the goggles are playing, the indicator light will be on. When the goggles are playing back in a random order, the indicator light will be flashing.

The light program loops around to the beginning once it has reached the end. There are 120 patches.

When the batteries begin to die, the color balance will shift. In particular, the red channel will become dim. The goggles will continue to operate with low batteries, although the colors will change slightly. When the batteries get low enough, you may experience unpredictable behavior, such as random restarts. There goggles are not damaged from running with low batteries, but you should replace dying batteries when possible for optimal performance.

P

I

I
P

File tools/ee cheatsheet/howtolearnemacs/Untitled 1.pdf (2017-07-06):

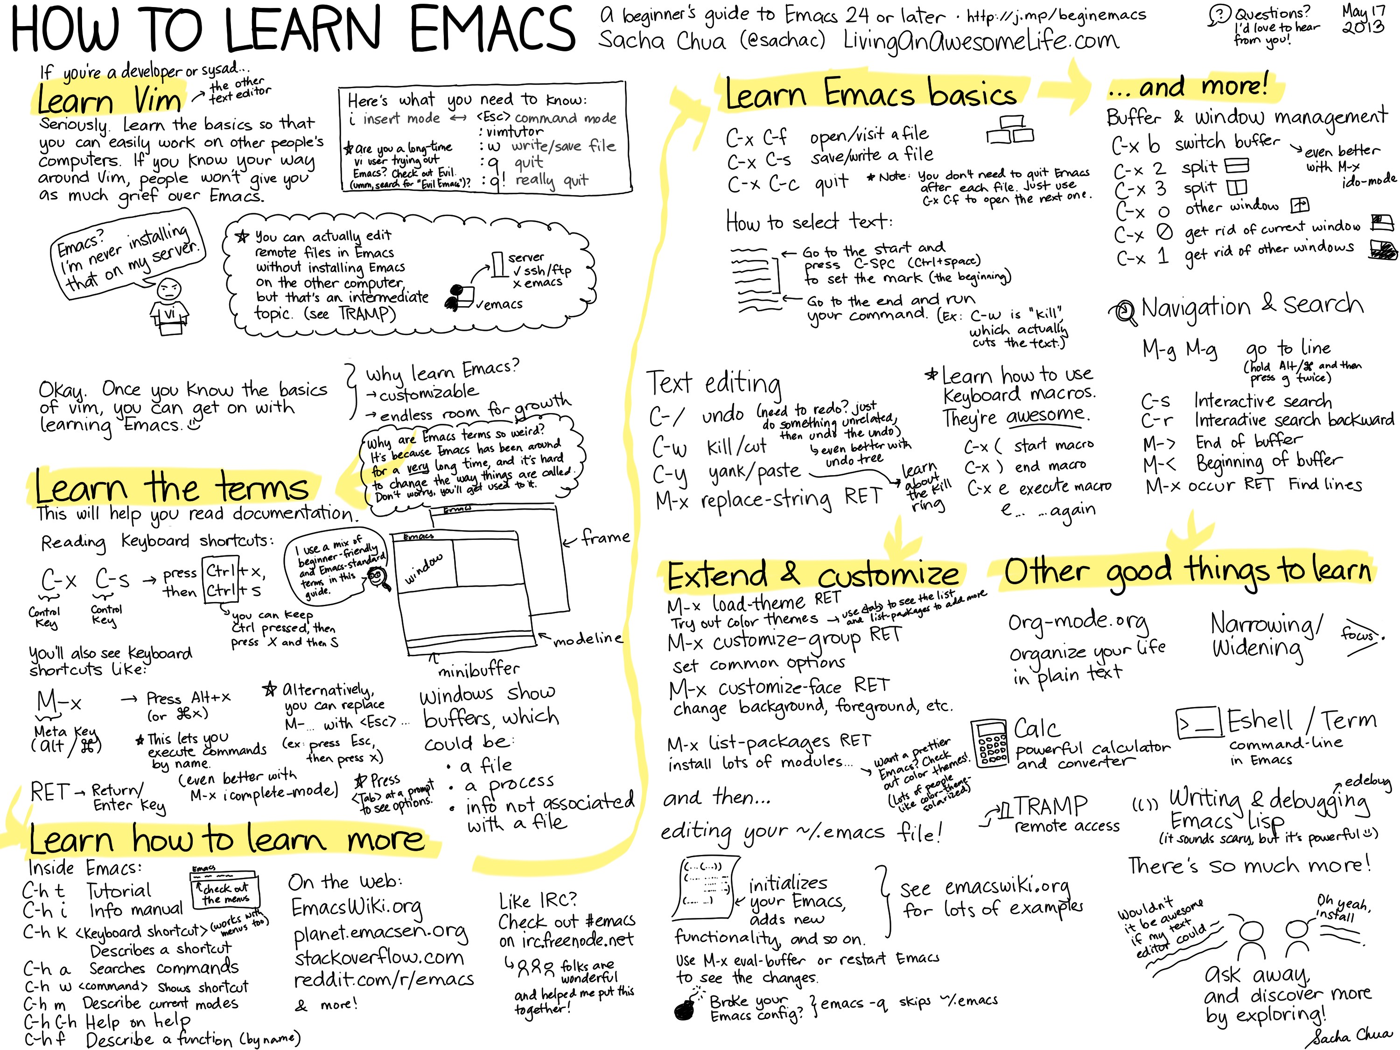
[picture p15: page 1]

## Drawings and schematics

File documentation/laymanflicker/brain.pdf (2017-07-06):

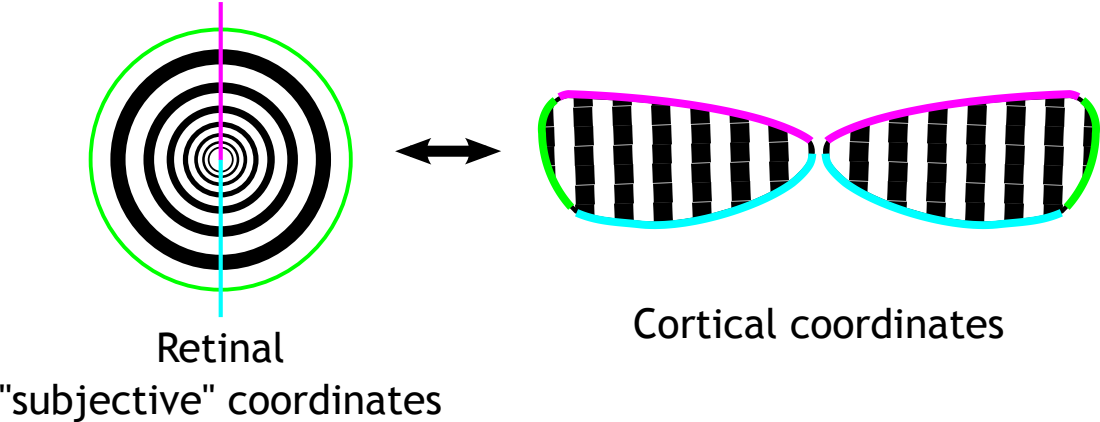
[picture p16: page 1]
Retinal "subjective" coordinates; Cortical coordinates

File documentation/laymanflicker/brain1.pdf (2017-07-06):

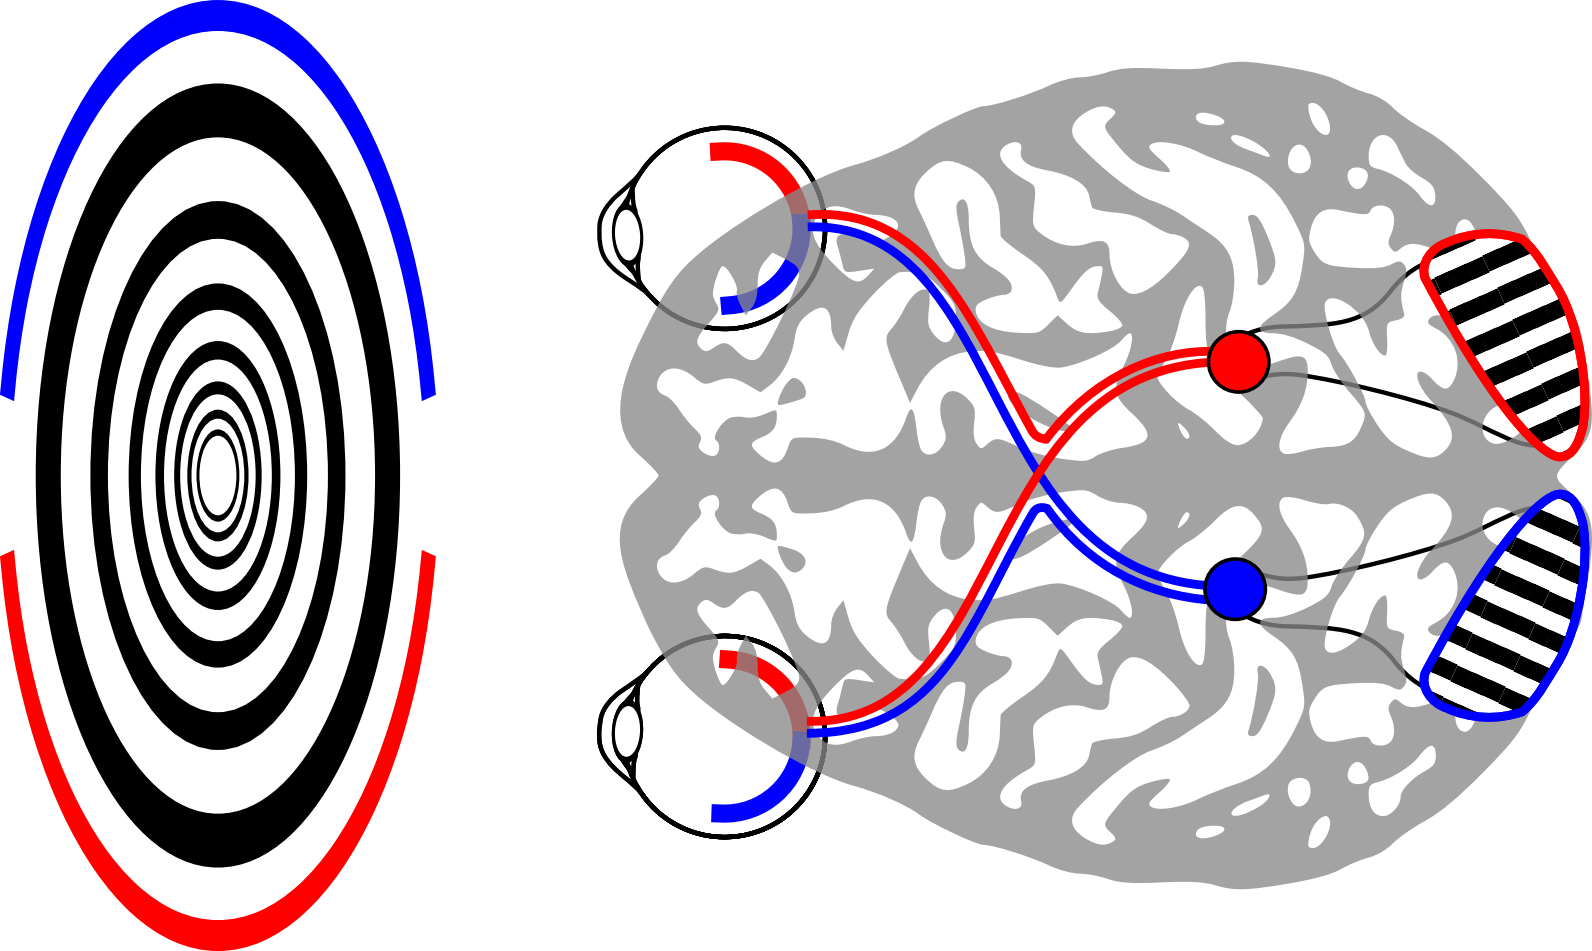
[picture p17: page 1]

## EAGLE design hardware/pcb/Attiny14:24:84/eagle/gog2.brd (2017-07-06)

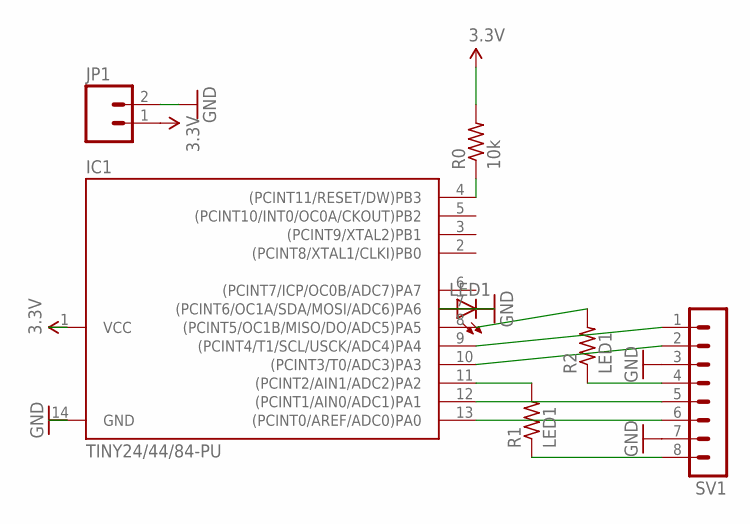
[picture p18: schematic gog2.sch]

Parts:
IC1: TINY24/44/84-PU; DIL14
JP1: M02; 1X02_LONGPADS
LED1: LED3MM
R0: 10k; 0207/7
R1, R2: LED1; 0207/7
SV1: MA08-1

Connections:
3.3V: IC1.1 (VCC), JP1.1, R0.2
GND: IC1.14 (GND), JP1.2, LED1.K (C), SV1.3, SV1.7
MISO: IC1.8 ((PCINT5/OC1B/MISO/DO/ADC5)PA5), R2.2
unnamed: IC1.7 ((PCINT6/OC1A/SDA/MOSI/ADC6)PA6), LED1.A
unnamed: IC1.11 ((PCINT2/AIN1/ADC2)PA2), R1.2
unnamed: R2.1, SV1.4
unnamed: R1.1, SV1.8
unnamed: IC1.13 ((PCINT0/AREF/ADC0)PA0), SV1.6
unnamed: IC1.12 ((PCINT1/AIN0/ADC1)PA1), SV1.5
unnamed: IC1.10 ((PCINT3/T0/ADC3)PA3), SV1.2
RESET: IC1.4 ((PCINT11/RESET/DW)PB3), R0.1
SCK: IC1.9 ((PCINT4/T1/SCL/USCK/ADC4)PA4), SV1.1

Board: 2 copper layers, 7 parts (1 on the bottom side), 12 nets, no tracks yet.

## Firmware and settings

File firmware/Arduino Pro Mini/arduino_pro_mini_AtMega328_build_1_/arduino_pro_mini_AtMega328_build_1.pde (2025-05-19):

#include <avr/pgmspace.h> //permits storing constant arrays in flash, giving us more RAM

/** Documentation
 *  Contents of this comment : 
 *  1 : Changes since last version
 *  2 : A note about representing things that arent integers on a 16 bit microcontroller
 *  3 : Light program language
 *  4 : layout of the remainder of this document
 *  
 *--- 0 : 20250503 Changes ------------------------------------------------------------
 *  I'm revisiting this 15 years later, trying to get the old Arduino pro-mini goggles
 *  builds to run again. 
 * 
 *  
 * 
 * 
 *--- 1 : Changes since last version --------------------------------------------------
 *  I made a few changes to the program, but the underlying structure is the same
 *  Superficial changes include making a new driver for the 4 character display, and
 *  defining some constants for use in the light program, to make things more readable.
 *
 *  The new display driver can scroll strings across the display. This is entertaining
 *  but is not used for anything important at the moment.
 *
 *  I also implemented Sine waveform lights ( which appear to be slightly less 
 *  effective at inducing geometric hallucinations ).
 *
 *  I added versions of the constant, squarewave, and sinewave lights that take
 *  six channels, RGB for the left and then RGB for the right eye. Patches that flash
 *  different colors, frequencies, or phases to different eyes produce amusing 
 *  effects ( well, no, not really, just different. disagreememnt between the inputs
 *  to the left and right eyes seem to weaken the ability to form patterns, at least
 *  to me)
 *
 *  I moved the light program into flash, so the program can now be much longer
 *  without filling up the RAM.
 *
 *  You no longer need to manually count the number of lights and change a constant
 *  to make the program work.
 *
 *  I removed a feature from the rendering code that normalized the light
 *  intensity per number of lights in a patch. This fixes a bug where in order
 *  to, say, alternate red and green lights, you would need to define two lights.
 *  the automatic normalization would then adjust both of these lights to half
 *  intensity. This creates the problem of making sure that the amplitude of the
 *  sum of lights in all channels never exceeds 255. For single light patches this 
 *  sould not be an issue. For multiple lights that may interfere, you will need to
 *  manually adjust light intensity so that the sum of the peaks of all waves is
 *  always less than 255 in all channels.
 *
 *  I have also restructured the program in a (slghtly) better way. Now intead of
 *  diving into a function which plays light patches, we crudely separate the work
 *  into a "light rendering thread" and a "display rendering thread", which are 
 *  interleaved in the main loop. This form of hard coded multithreading is common
 *  in embedded systems. New threads ( perhaps to poll input hardware or talk to 
 *  a computer attached to USB ) can be added to the main loop. At the moment all
 *  functions called from the main loop must usually take less than 10 ms, otherwise
 *  the light rendering will noticably stall.
 *
 *
 *--- 2 : A note about representing things that aren't ints on a 16 bit microcontroller
 *  The ATmega168 which drives your current version of the goggles can only perform 
 *  computations on up to 16 bit integers, no floating point is supported. 
 *  Because of this, in several points in the program, we use some number of low order bits
 *  as fractional bits to emulate fixed point decimal representations. This is done in a rather
 *  ad-hoc fasion, depending on the range of values we wish ro represent.
 * 
 *  Color values for R,G,B are in the range [0,1). This range is mapped to [0,255].
 *  multiplication of color values is provided by the FLOAT8MUL macro
 * 
 *  Frequency values are in the range [0,63] Hz and are mapped onto [0,255].
 *  This means that representations of the frequency code will appear to be 4x their
 *  actual value
 *
 *  Time durations of patches range from [0,31] and are mapped to [0,255].
 *  This means that representations of the duration of a patch will appear in units
 *  of one eights of a second. In hexidecimal notation, the second least significant
 *  digit will count half seconds, so that 0x40 represent 8 seconds.
 *
 *  Phase, in the range of [0,2*pi) is mapped to [0,255]. A phase shift of
 *  128 is equal to 180 degrees, 64 is equal to 90 degrees, and so on and so forth
 * 
 *  The output of the sine function [-1,1] is mapped to [0,255]
 *  is is convenient for generating sine wave output immediately suitable for display
 * 
 *  
 *--- 3 : Light Program Language ------------------------------------------------------
 * The goggles generate color based on a program stored in the flash array 
 * "program". This program consists of a series of patches. Patches are 
 * played in series, sequentially, until the end of the program. The program
 * starts over again once it is finished. Each patch begins with a byte
 * identifying the type of patch. The byte 0xff signals the end of the program.
 * All patches begin with a type identifier followed by a duration, measured
 * in eighths of a second. Data specific to different patch types follows.
 *
 * Currently Defined Types of Patch
 * 1 : default type : a collection of lights
 *     1 byte patch type ( which defines where to look for data )
 *     1 byte T the time duration in eigth seconds of the patch ( up to 32 seconds )  
 *     1 byte L number of active lights ( up to MAXLIGHTS )
 *     L light structs each with
 *       1 byte waveform type, which implies number and types of X bytes of parameters
 *       X bytes of parameters ( up to MAXPARAMS )
 *     next light up to L
 * 0 : patch link HARD TO USE, TODO : WRITE LIGHT PROGRAM GUI + "Compiler" 
 *     1 byte patch type ( which defines where to look for data )
 *     1 byte T the time duration in eighth seconds of the patch ( up to 32 seconds )  
 *     2 byte int referencing the header of a default patch
 * 255 : not a patch, but the end of the program ( loop back to beginning )
 *
 * The default patch type consist of a set of lights. There are many different
 * types of lights, with different parameters.  
 *
 *
 * Currently Defined Types of Light
 * 0 : 3 channel Constant 
 *     3 bytes of state [R,G,B]
 * 1 : 3 channel Square wave
 *     5 bytes of state [R,G,B,f,p]
 *       6 bytes of RGB (3 left, 3 right) color
 *       1 bytes frequency in quarter Hz
 *       1 bytes is a phase shift in 1/256ths of a cycle
 *       1 bytes cycle 255 = full 0 = off 128 = half //DUTY CYCLE NOT IMPLEMENTED !! IGNORE (TODO : IMPLEMENT IT)
 * 2 : 3 channel Sine wave
 *     5 bytes of state [R,G,B,f,p]
 *       6 bytes of RGB (3 left, 3 right) color
 *       1 bytes frequency in quarter Hz
 *       1 bytes is a phase shift in 1/256ths of a cycle
 * 3 : 6 channel Constant 
 *     6 bytes of state [Rl,Gl,Bl,Rr,Gr,Br]
 * 4 : 6 channel Square wave
 *     8 bytes of state [Rl,Gl,Bl,Rr,Gr,Br,f,p]
 *       6 bytes of RGB (3 left, 3 right) color
 *       1 bytes frequency in quarter Hz
 *       1 bytes is a phase shift in 1/256ths of a cycle
 *       1 bytes cycle 255 = full 0 = off 128 = half //DUTY CYCLE NOT IMPLEMENTED !! IGNORE (TODO : IMPLEMENT IT)
 * 5 : 6 channel Sine wave
 *     8 bytes of state [Rl,Gl,Bl,Rr,Gr,Br,f,p]
 *       6 bytes of RGB (3 left, 3 right) color
 *       1 bytes frequency in quarter Hz
 *       1 bytes is a phase shift in 1/256ths of a cycle
 * 
 * 7 segment LED notation
 * 0     _
 * 123  |_|
 * 456  |_|
 *
 *
 *--- 4 : Layout of the remainder of this document ------------------------------------
 * 
 * Light program readability #defines
 * Light program array
 * Lookup tables ( Sinewave, light type lengths & display lookup )
 * Program #defines
 * Program global variables & state
 * Main program logic ( setup & light rendering code )
 * Other utility functions
 * Display logic ( drivers and string functions )
 */
 
//////////////////////////////////////////////////////////////////////////////////////////////////////////////
///////  Light program readability #defines  /////////////////////////////////////////////////////////////////
//////////////////////////////////////////////////////////////////////////////////////////////////////////////
#define PATCH             (0x01)
#define END               (0xff)
#define CONSTANT          (0x00)
#define LINK              (0x00)
#define SQUARE            (0x01)
#define SINE              (0x02)
#define CONSTANT_6CHANNEL (0x03)
#define SQUARE_6CHANNEL   (0x04)
#define SINE_6CHANNEL     (0x05)

//////////////////////////////////////////////////////////////////////////////////////////////////////////////
///////  Light program array  ////////////////////////////////////////////////////////////////////////////////
//////////////////////////////////////////////////////////////////////////////////////////////////////////////
PROGMEM prog_uchar program[] = 
{
  
  //example : long grey ( for whitepoint adjustment )
  PATCH, 0x10, 1, CONSTANT, 255, 255, 255,
  
  //example : 15 Hz white square wave strobe for 4 seconds
  PATCH, 0x20, 1,
  SQUARE, 0xaf, 0xaf, 0xaf, 60, 0,
  
  //example : 14.75 Hz orange sinewave strobe for 3 seconds
  PATCH, 0x18, 1,
  SINE, 0xff, 0x80, 0x00, 59, 0,
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
void loop() {
  writeNumberDec(patchID, count++);
  renderFrame();
  if ( millis() >= stopTime )
    loadNextPatch();
}

void loadNextPatch() {
  byte patchType = readProgram(CPatch) ;
  long patchTime = (long)(readProgram(CPatch + 1))*(long)1000>>3; //convert patch duration into milliseconds
  long startTime = millis();
  stopTime  = startTime + patchTime ;
  switch (patchType) {
  case 0 :
    doPatch( *((int *)(readProgram(CPatch + 2))) );
    CPatch = CPatch + 4;
    patchID++; 
    break; 
  case 1 :
    CPatch = doPatch( CPatch ) ;
    patchID ++ ;
    break;
  default : //end of program
    CPatch  = 0 ;
    patchID = 0 ;
    break;
  }
}

int doPatch( int CPatch ) {
  NLight = readProgram(CPatch + 2) ;
  CLight = CPatch + 3 ;
  for ( int light = 0 ; light < NLight ; light ++ ) {
    int storeIndex = light*MAXPARAMS ;
    for ( int i = 0 ; i < MAXPARAMS ; i ++ )
      lights[storeIndex + i] = readProgram(CLight + i);
    CLight += lightSize[lights[storeIndex]];
  }
  return CLight;
}

void renderFrame() {
    long time = millis()<<6; //im sure the 6 is there fore a reason...
    int RGB[6] = {0,0,0,0,0,0};
    for ( int light=0; light<NLight; light++ )
    {
      int i = light*MAXPARAMS+1;
      switch ( lights[i-1] ) {
      case CONSTANT : // constant
        for (int c=0; c<3; c++) {
          int color = lights[i+c];
          RGB[c  ] += color;
          RGB[c+3] += color;
        }
        break ;
      case SQUARE : { // Square wave
          byte F = (lights[i+3]); //frequency
          byte P = (lights[i+4]); //phase
          byte V = 0xff*(((FLOAT8MUL(F,time)>>2)+P>>7)&0x1); //compute amplitude
          for (int c=0; c<3; c++) {
            int color = FLOAT8MUL(lights[i+c],V);
            RGB[c  ]+=color;
            RGB[c+3]+=color;
          }
        }
        break;
      case SINE : {// Sine wave
          byte F = (lights[i+3]); //frequency
          byte P = (lights[i+4]); //phase
          int V = sine((F*millis()>>4)+P); //compute amplitude
          for (int c=0; c<3; c++) {
            int color = FLOAT8MUL(lights[i+c],V);
            RGB[c  ]+=color;
            RGB[c+3]+=color;
          }
        }
        break ; 
      case CONSTANT_6CHANNEL : // constant ( 6 channels )
        for (int c=0; c<6; c++)
          RGB[c]+=lights[i+c];
        break ;
      case SQUARE_6CHANNEL : { // Square wave ( 6 channels )
          int F = (lights[i+6]); //frequency
          int P = (lights[i+7]); //phase
          int V = 0xff*((((FLOAT8MUL(F,time)>>2)+P)>>7)&0x1); //compute amplitude
          for (int c=0; c<6; c++)
            RGB[c]+=FLOAT8MUL(lights[i+c],V);
        }
        break;
      case SINE_6CHANNEL : { // Sine wave ( 6 channels )
          int F = (lights[i+6]); //frequency
          int P = (lights[i+7]); //phase
          int V = sine((F*millis()>>4)+P); //compute amplitude
          for (int c=0; c<6; c++)
            RGB[c]+=FLOAT8MUL(lights[i+c],V);
        }
        break ; 
      }
    }
    writeColorArray(RGB);
  }


//////////////////////////////////////////////////////////////////////////////////////////////////////////////
///////  Other utility functions  ////////////////////////////////////////////////////////////////////////////
//////////////////////////////////////////////////////////////////////////////////////////////////////////////

int readProgram(int index) {
  return pgm_read_byte(&program[index]);
}

// something that resembles a sine funtion
int sine(int n) {
  return pgm_read_byte(&lookupsine[n&0xff]);
}

void errorstate() {
  writeColor( 0xff, 0xff, 0x00, 0x00, 0xff, 0xff );
  delay(500);
  writeColor( 0x00, 0xff, 0xff, 0xff, 0xff, 0x00 );
  delay(500);
}

/** writeColor performs whitepoint adjustment then write a color to 
 *  the eyes. Left and Right eyes are specified independently
 */
void writeColor(int Rl, int Gl, int Bl, int Rr, int Gr, int Br) {
  analogWrite(R1pin, (byte)FLOAT8MUL(Rl,RLscale) ); 
  analogWrite(G1pin, (byte)FLOAT8MUL(Gl,GLscale) ); 
  analogWrite(B1pin, (byte)FLOAT8MUL(Bl,BLscale) ); 
  analogWrite(R2pin, (byte)FLOAT8MUL(Rr,RRscale) ); 
  analogWrite(G2pin, (byte)FLOAT8MUL(Gr,GRscale) ); 
  analogWrite(B2pin, (byte)FLOAT8MUL(Br,BRscale) ); 
}


/** writeColorArray performs whitepoint adjustment then write a color to 
 *  the eyes. Left and Right eyes are specified independently 
 *  @param RGB an array of six integers, RGB for left and then right eye
 */
void writeColorArray(int RGB[6]) {
  for (int c=0; c<6; c++)
    analogWrite(COLORPIN[c],(byte)FLOAT8MUL(RGB[c],SCALE[c]));
}

//////////////////////////////////////////////////////////////////////////////////////////////////////////////
///////  Display logic ( drivers and string functions )  /////////////////////////////////////////////////////
//////////////////////////////////////////////////////////////////////////////////////////////////////////////

/** writeNumber will write a number to the numerical display.
 *  digits are multiplexed. Which digit gets writtin
 *  depends on the parity of cycle 
 */
void writeNumberHex( int number, int cycle ) {
  number>>=(4*(cycle&3));
  number=DIGITS[number&15];
  for (int i=0;i<4;i++) //clear cathodes
    digitalWrite(LINE[i],HIGH);
  for(int i=0; i<7; i++) {
    digitalWrite( CELL[i], (number&1)? HIGH : LOW );
    number>>=1;
  }
  digitalWrite(LINE[cycle&3], LOW );
}

/** writeNumber will write a number to the numerical display.
 *  digits are multiplexed. Which digit gets writtin
 *  depends on the parity of cycle 
 */
void writeNumberDec( int number, int cycle ) {
  int digit = cycle&3;
  for(int i=0; i<digit; i++)
    number/=10;
  number=DIGITS[number%10];
  for (int i=0;i<4;i++) //clear cathodes
    digitalWrite(LINE[i],HIGH);
  for(int i=0; i<7; i++) {
    digitalWrite( CELL[i], (number&1)? HIGH : LOW );
    number>>=1;
  }
  digitalWrite(LINE[cycle&3], LOW );
}

/** scrollString will scroll a string across the display from left to right
 *  letters are only approximately represented, with M,W,K, and X being 
 *  very poorly rendered. 'v' also doesn't look great
 *
 *  @param string string to scroll
 *  @param length lenght of string to scroll
 *  @param cycle program iteration ( for scanning multiplexed array )
 *  @param msrate time delay in milliseconds before scrolling
 *  @return 1 if string has been fully displayed, else 0
 */
int scrollString(char *string, int length, int cycle, int msrate ) {
  int i = cycle&3 ;
  int frame = millis()/msrate;
  int auglen = length+5;
  int code = frame%auglen-i;
  code = code<length && code>=0 ? string[code] : ' ';
  code = ASCII[ code<32 || code>126? 0 : code-32 ];
  for (int i=0; i<4; i++) //clear cathodes
    digitalWrite( LINE[i], HIGH);
  for (int i=0; i<7; i++) {
    digitalWrite( CELL[i], code&1?HIGH:LOW );
    code>>=1;
  }
  digitalWrite( LINE[i], LOW );
  return frame>=auglen;
}

/** strlen computes the length of a well formed null terminated string
 *  @param str string to find the length of
 */
int strlen(char *str) {
  int len = 0;
  int i = 0;
  while (str[i++]!=0) len++ ;
  return len;
} 

char *string ="- - HEllo   CItIzEnS Of SPACEsHIp EArth - tHIs IS your CAptAIn - your CAptAIn IS DEAD - rELIGI0n IS A viruS of thE S0UL And SHALL bE ErAdICAtEd bEf0rE it CAn P0LLUtE Us All - It is LEFT to us - AlonE on EArth - to rebel Against the tyranny of the selfish replicators";

/** setup_diplay initialized the LED display driver
 */
void setup_display() {
  for (int i=0;i<20;i++)
    pinMode(i,OUTPUT);
}

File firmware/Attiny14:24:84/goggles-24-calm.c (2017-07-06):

/*
Hardware notes
==============

DDRx   : 1 = output, 0 = input
PORTx : output buffer
PINx  : digital input buffer ( writes set pullups )
Port B is the chip IO port ( other ports are control registers )

    AtTiny24 pinout:
                __ __
    3     VCC -|  U  |- GND    1
      BCK PB0 -|     |- PA0 G1
      SHU PB1 -|     |- PA1 B1
    4 RST PB3 -|     |- PA2 R1
      PLY PB2 -|     |- PA3 G2 
      FWD PA7 -|     |- PA4 B2 5
    2 IND PA6 -|_____|- PA5 R2 6
            
    Programmer pinout, 6 pin:
            
    6 MISO +-+  VCC 3
    5 SCK  + + MOSI 2 
    4 RST  +-+  GND 1
    
    Programmer pinout, 10 pin:
            
    3 vcc  +-+   MOSI 2
           + +    
           + +]  RST  4 
           + +   SCK  5 
    1 gnd  +-+   MISO 6

    Circuit:
                __ __
           VCC-|  U  |-GND
        GND-/ -|     |-----\
        GND-/ -|     |------(RGB1)-GND
       VCC-www-|     |-www-/
        GNd-/ -|     |-----\
        GNd-/ -|     |------(RGB2)-GND
    GND-(LED1)-|_____|-www-/

    VCC-(LED0)-GND

Here is a diagram of the circuit board :
 
              R-GBR-GB
     _________||||||||___
    |o+++++++ |  ||  |  o|
    | +++++++ |__||__|(i)|
    |= [x] [<] [=] [>](p)|
    |o__________________o|

The buttons are as follows, from left to right :

[x] Shuffle      : if playing, toggle shuffled playback, else skip to random
[<] Skip Back    : skips to the previous light patch
[=] Play/Pause   : toggles automatic advancing through patches
[>] Skip Forward : advances to the next light patch
 
The LEDs indicate :
 (i) -- indicator LED. on if playing, flashing if playing+shuffle
 (p) -- power LED, on if powered on. 
 
When powered on, the goggles are paused at patch zero. Press play/pause to 
begin the default light sequence. Press forward and back to move through the
light patches when paused or playing. Press shuffle to skip to a random 
patch when paused, or press shuffle when playing to toggle whether or not
patches are played in a random order. When the goggles are paused, the
indicator light will be off. When the goggles are playing, the indicator
light will be on. When the goggles are playing back in a random order, the
indicator light will be flashing. The light program loops around to the 
beginning once it has reached the end. There are 123 patches, though not all
are unique.

╱╲
╲╱╲
  ╱
 
 
╱╲
╲╱╲
 ╲╱
 
 
╱╲
  ╲
   
 
╱ 
╲╱╲
 ╲╱
 
 
╱ 
╲╱╲
  ╱
 
 
 ╲
╲╱╲
   
 
 
╱╲
 ╱╲
  ╱
 
 
╱╲
 ╱ 
 ╲╱
 
 
 ╲
  ╲
   
 
╱╲
╲ ╲
 ╲╱
 
 
 
 
*/


// STANDARD DEFINITIONS
#define HIGH   1
#define LOW    0
#define INPUT  0
#define OUTPUT 1
#define HI   HIGH
#define LO   LO
#define IN   INPUT
#define OUT  OUTPUT
#define NOP (__no_operation())
#define DIGITAL_OUT_PORT PORTA
#define DIGITAL_IN_PORT  PINA
#define DIGITAL_DIRECTION_PORT DDRA
#define inp(port) (port)
#define outp(val, port) (port)=(val)
#define inb(port) (port)
#define outb(port, val) (port)=(val)
#define sbi(port, bit) (port)|=(1<<(bit))
#define cbi(port, bit) (port)&=~(1<<(bit)) 
#define PINMODES(MODES) (DIGITAL_DIRECTION_PORT=(MODES))
#define PIN_MODE(PIN,MODE) (PINMODES(DIGITAL_DIRECTION_PORT&~(1<<(PIN))|((MODE)<<(PIN))))
#define DIGITAL_WRITE_HI(PINS) (DIGITAL_OUT_PORT|=(PINS))
#define DIGITAL_WRITEXOR(PINS) (DIGITAL_IN_PORT=(PINS))
#define DIGITAL_WRITEALL(PINS) (DIGITAL_OUT_PORT=(PINS))
#define DIGITAL_WRITELOW(PINS) (DIGITAL_OUT_PORT&=~(PINS))
#define DIGITAL_OUT_STAT()     (DIGITAL_OUT_PORT)
#define DIGITAL_WRITE(PIN,VAL) (DIGITAL_OUT_PORT=(DIGITAL_OUT_PORT&~(1<<(PIN)))|((VAL)<<(PIN)))
#define DIGITAL_READALL() (DIGITAL_IN_PORT)
#define DIGITAL_READ(PIN) ((DIGITAL_IN_PORT>>(PIN))&1)
#define ever (;;)
#define pinMode PIN_MODE
#define digitalWrite DIGITAL_WRITE

// define the processor speed if it's not been defined at the compiler's 
// command line. So, it doesn't really matter what these values are
// all that matters is that the combination causes 0xff to 
// correspond to the correct frequency of strobe
// where "correct" is whatever you feel like the slowest frequency should be
// presently its set so that 512 minitics equals about 1 second,
// so, I guess thats about 2 milliseconds
#define DELAYMS 27
#include <avr/pgmspace.h>
#include <avr/io.h>

//remember, 1KB is the limit
//that 1024 bytes ! -- 2048 is the limit now!
//conservatively, this means no more than 512 bytes light program
//which probably means approximately 50-60 patches
#define N1 (1<<5)
#define N2 (2<<5)
#define N3 (3<<5)
#define N4 (4<<5)
#define N5 (5<<5)
#define N6 (6<<5)
#define N7 (7<<5)
#define N8 (8<<5)

#define MAXLIGHTS  7
#define LIGHTBYTES 4

//0x00 is actually 0x100 here, because 0x00 doesn't mean anything
//if DELAYMS is set such that 1 tic = 1/510th of a second
//equivalently : so that on/off = 0xff = 1Hz
//then setting this to 0x80 gives a megatic duration of about quarter
//second, which gives a max patch duration of about 32 seconds.
#define TICS_PER_MEGATIC 0xff

//PWM bit mask patterns
#define LEVEL0 0x00
#define LEVEL1 0x01
#define LEVEL2 0x11
#define LEVEL3 0x29
#define LEVEL4 0x55
#define LEVEL5 0x75
#define LEVEL6 0x77
#define LEVEL7 0xEF
#define LEVEL8 0xFF 
uint8_t level[8] = {LEVEL0,LEVEL1,LEVEL2,LEVEL3,LEVEL4,LEVEL5,LEVEL6,LEVEL7};
uint8_t blue_level[4] = {LEVEL0,LEVEL2,LEVEL4,LEVEL7};

//8-bit color masks and alignment offsets
#define R8MASK  ((uint8_t)0xE0)
#define G8MASK  ((uint8_t)0x1C)
#define B8MASK  ((uint8_t)0x03)
#define R16MASK ((uint16_t)0x7C00)
#define G16MASK ((uint16_t)0x03E0)
#define B16MASK ((uint16_t)0x001F)

// COLOR DEFINITIONS
#define RED           (7<<5)
#define GREEN         (7<<2)
#define BLUE          (3)
#define MEDIUM_RED    (5<<5)
#define MEDIUM_GREEN  (5<<2)
#define MEDIUM_BLUE   (2)
#define DARK_RED      (3<<5)
#define DARK_GREEN    (3<<2)
#define DARK_BLUE     (1)
#define FAINT_RED     (1<<5)
#define FAINT_GREEN   (2<<2)
#define FAINT_BLUE    MEDIUM_BLUE
#define WHITE         (RED|GREEN|BLUE)
#define GREY          ((2<<5)|(2<<2)|(1))
#define YELLOW        (RED|GREEN)
#define MAGENTA       (RED|BLUE)
#define CYAN          (BLUE|GREEN)
#define YELLOW_GREEN  (DARK_RED|GREEN)
#define DEEP_YELLOW   (DARK_GREEN|DARK_RED)
#define DEEP_CYAN     (DARK_GREEN|DARK_BLUE)
#define DEEP_MAGENTA  (DARK_RED|DARK_BLUE)
#define BROWN         DEEP_YELLOW
#define ORANGE        (RED|DARK_GREEN)
#define PURPLE        (BLUE|DARK_RED)
#define VERDE         (GREEN|DARK_BLUE)
#define PINK          (RED|DARK_BLUE)
#define AQUA          (BLUE|DARK_GREEN)
#define RED_ORANGE    (RED|FAINT_GREEN)
#define YELLOW_ORANGE (RED|MEDIUM_GREEN)
#define DARK_ORANGE   (MEDIUM_RED|FAINT_GREEN)
#define MEDIUM_ORANGE (MEDIUM_RED|DARK_GREEN)
#define SKY           (BLUE|FAINT_RED|FAINT_GREEN)

//port states for application
#define PORTA_IO_STATE (0x7f) // 0 1 11 1111 ( forward, indicator, RGBRGB )
#define PORTA_PULL_UP  (~PORTA_IO_STATE)
#define PORTB_IO_STATE (0x07) // (voidx4) (reset) play shuffle back
#define PORTB_PULL_UP  7
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
